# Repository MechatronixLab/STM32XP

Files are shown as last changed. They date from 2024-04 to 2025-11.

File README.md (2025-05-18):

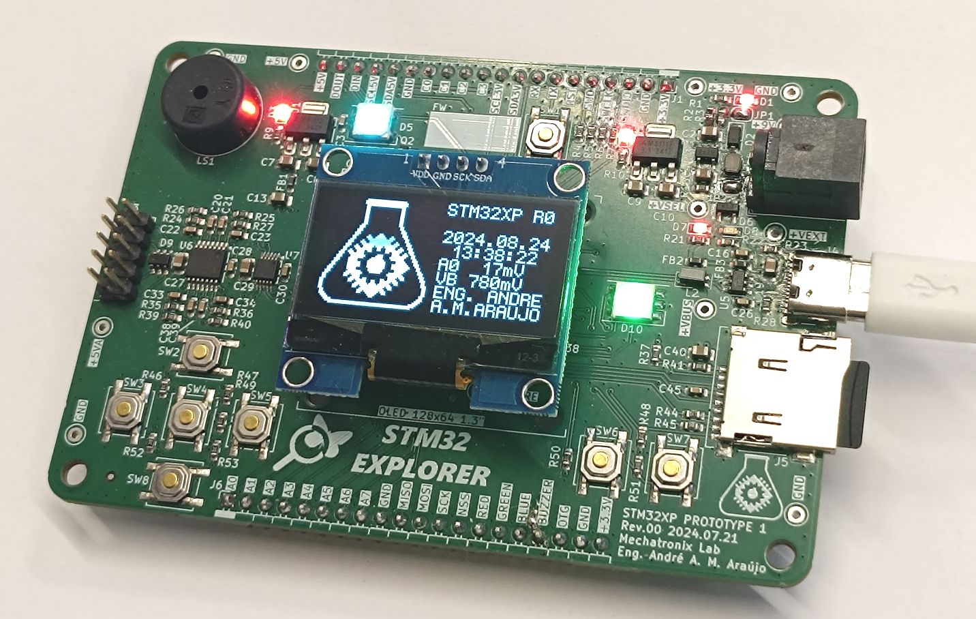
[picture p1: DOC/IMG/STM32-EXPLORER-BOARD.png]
STM32 EXPLORER BOARD


# STM32 Explorer Board - STM32XP
  
This is an educational development board conceived as part of a PCB Design course. The course is offered via [**Portal Embarcados**](https://embarcados.com.br/) website ([**Course Page**](https://cursos.embarcados.com.br/cursos/projeto-de-pcb-para-sistemas-embarcados/)).

## License and certification
This is an open source hardware project licensed under CERN-OHL-P. More details on [LICENSE.md](./LICENSE.md).  
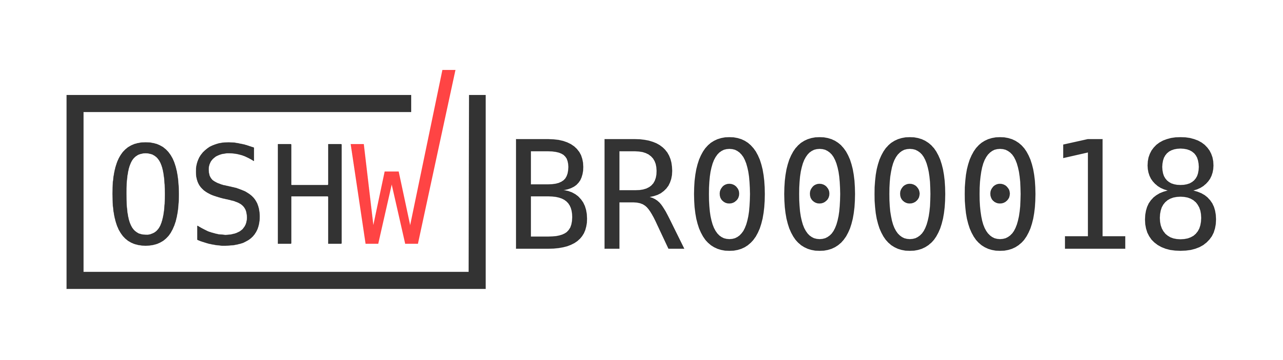
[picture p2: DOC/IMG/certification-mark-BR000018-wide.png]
OSHW BR000018

[OSHW] BR000018 | Certified open source hardware | [oshwa.org/cert](https://certification.oshwa.org/br000018.html).

## Board specifications

The board is based on the [**STM32F411**](https://www.st.com/en/microcontrollers-microprocessors/stm32f411.html), more specifically, the [**STM32F411RET6**](https://www.st.com/en/microcontrollers-microprocessors/stm32f411re.html).
Additionally, the board features some components commonly used in Embedded Systems, such as:
- DC-DC Converters
- OLED Display, connected to the MCU via I²C
- RGB LEDs
- Audio buzzer, controlled via PWM
- External ADC with analog antialiasing filters
- USB 1.1 Full Speed via a Type-C connector
- Micro SD Card for easy data storage, connected to the MCU via SPI
- Input buttons
- Several I/O pins routed to breakout connectors/pins
- CR2032 Battery for RTC operation

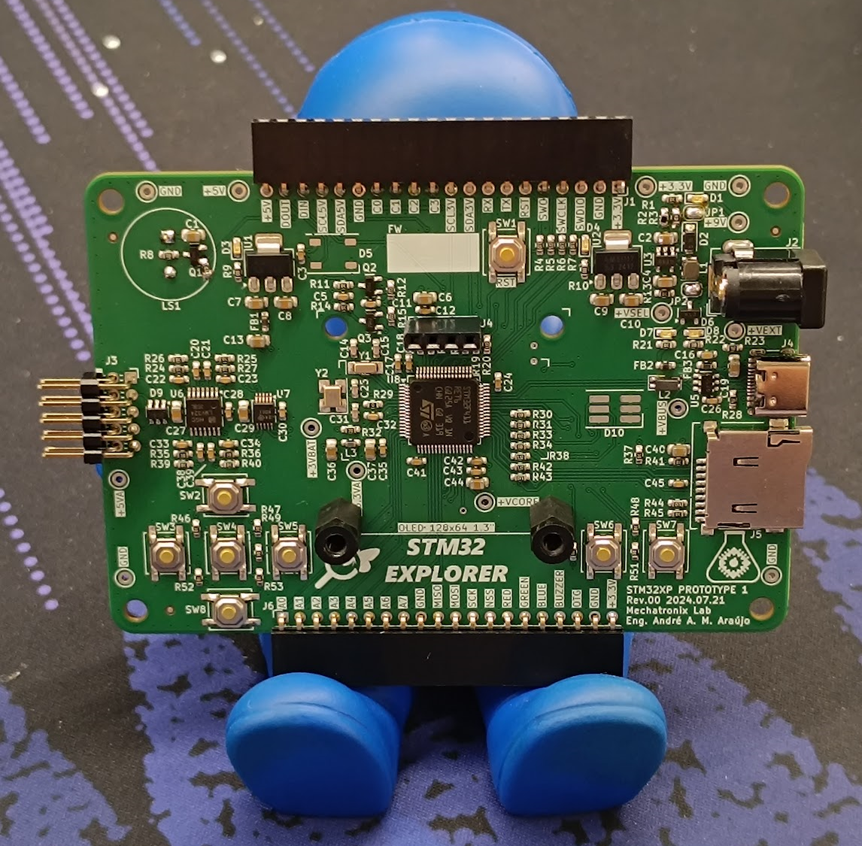
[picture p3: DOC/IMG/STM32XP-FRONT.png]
Front


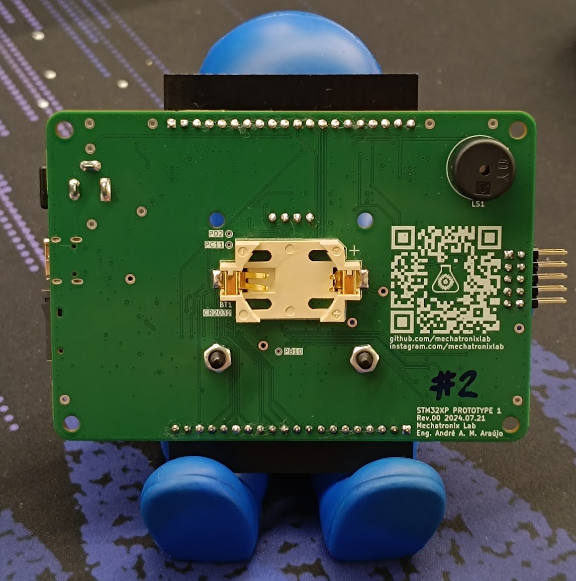
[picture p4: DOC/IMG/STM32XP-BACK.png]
Back

  
## Firmware

A simple software application was developed to test each of the subsystems of the board.

## Tests

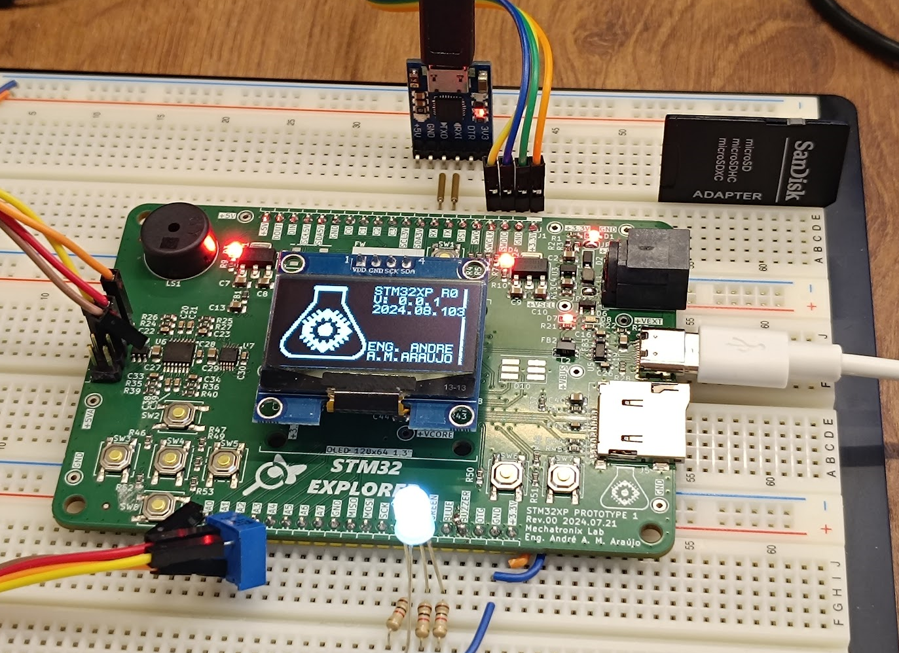
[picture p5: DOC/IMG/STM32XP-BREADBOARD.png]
Breadboard testing


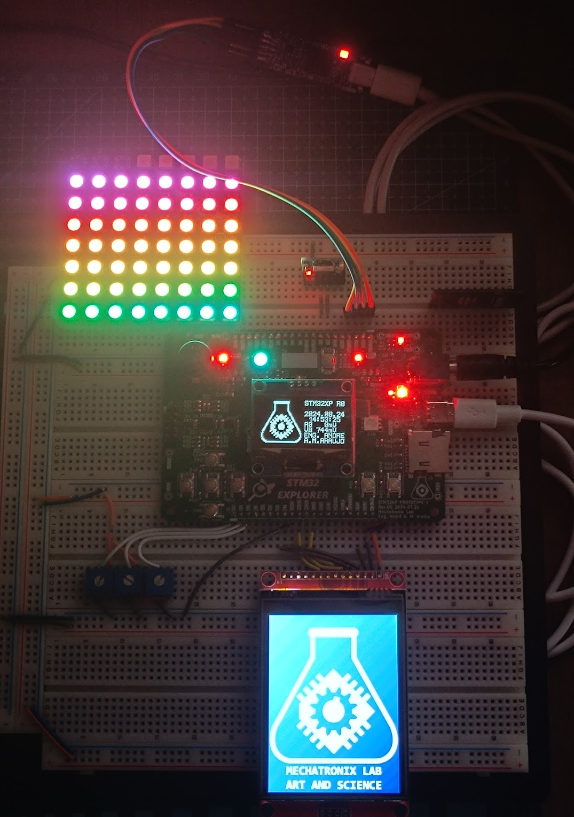
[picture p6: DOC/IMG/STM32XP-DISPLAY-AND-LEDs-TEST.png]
LCD Display and RGB LEDs tests


# Breadboard Prototype

Before commiting to this design, a breadboard prototype was assembled for validation. This prototype used a Nucleo Board, development modules whenever possible, ICs and discrete electronic components. These parts can be easily acquired on electronics stores worldwide. The connections between modules follow very closely the [final schematic](https://github.com/MechatronixLab/STM32XP/blob/master/HARDWARE/KICAD/STM32XP.pdf) of the STM32XP Board. The same firmware runs on both the prototype and STM32XP Board.

Breadboard Prototype  

## Parts list
 
| Part | Image |
|---|:---:|
| [**NUCLEO-F411RE**](https://www.st.com/en/evaluation-tools/nucleo-f411re.html) |  |
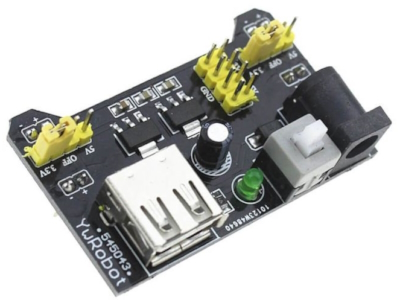
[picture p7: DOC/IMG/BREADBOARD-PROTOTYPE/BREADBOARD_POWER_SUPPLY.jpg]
| Breadboard Power Supply Module |  |
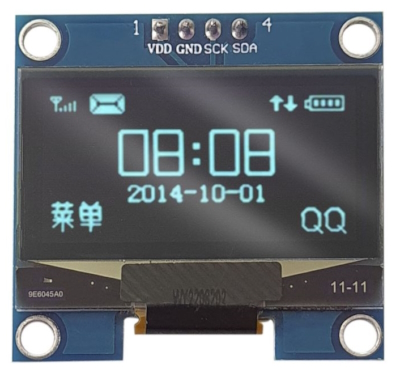
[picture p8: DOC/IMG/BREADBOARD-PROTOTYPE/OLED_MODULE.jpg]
| 1.3" OLED Display Module |  |
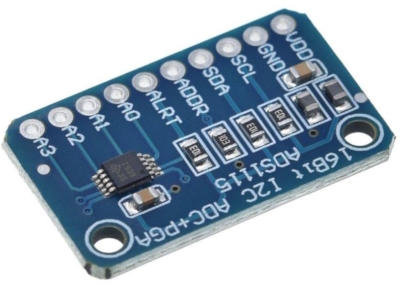
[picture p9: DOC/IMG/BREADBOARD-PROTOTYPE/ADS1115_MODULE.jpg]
| ADS1115 ADC Module |  |
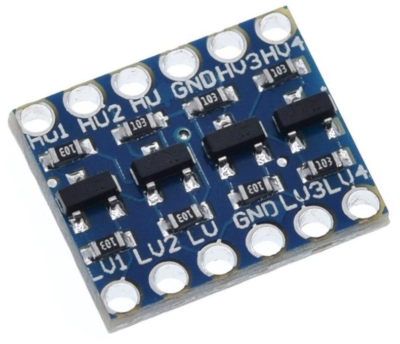
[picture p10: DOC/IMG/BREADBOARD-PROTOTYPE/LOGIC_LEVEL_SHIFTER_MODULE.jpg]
| Bidirectional Level Shifter Module |  |
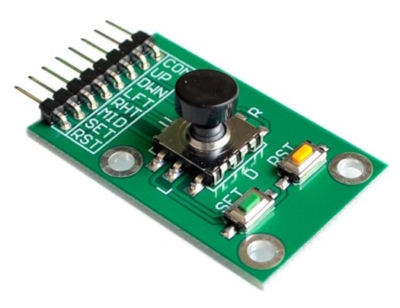
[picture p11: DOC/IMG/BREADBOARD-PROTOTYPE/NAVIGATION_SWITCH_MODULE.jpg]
| Directional Tactile Switch Module |  |
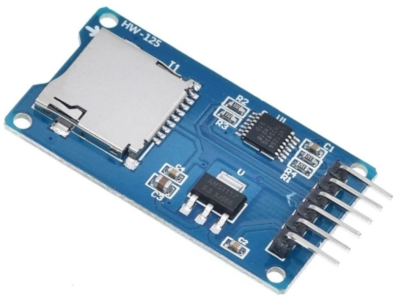
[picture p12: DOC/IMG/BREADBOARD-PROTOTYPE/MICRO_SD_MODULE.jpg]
| Micro SD Card Module |  |
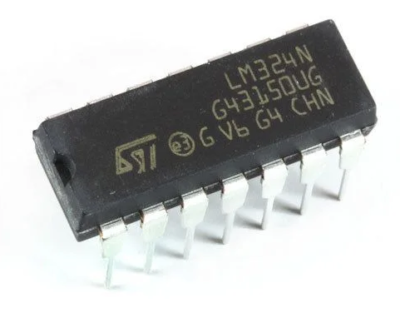
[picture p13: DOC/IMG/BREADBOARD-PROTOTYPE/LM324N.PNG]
| LM324N + Passives (Anti-Aliasing Filter) |  |
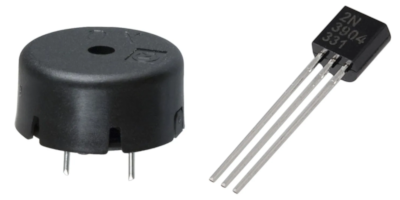
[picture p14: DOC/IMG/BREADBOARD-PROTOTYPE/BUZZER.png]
| Passive Buzzer + 2N3904 |  |
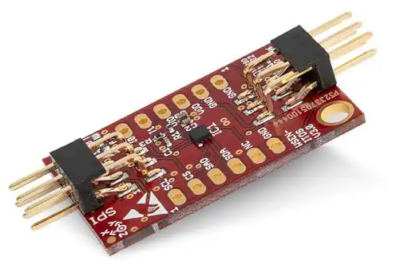
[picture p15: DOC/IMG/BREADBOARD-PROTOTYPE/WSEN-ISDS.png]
| [**WSEN-ISDS**](https://www.we-online.com/en/components/products/WSEN-ISDS) (Left out of the final design)|  |

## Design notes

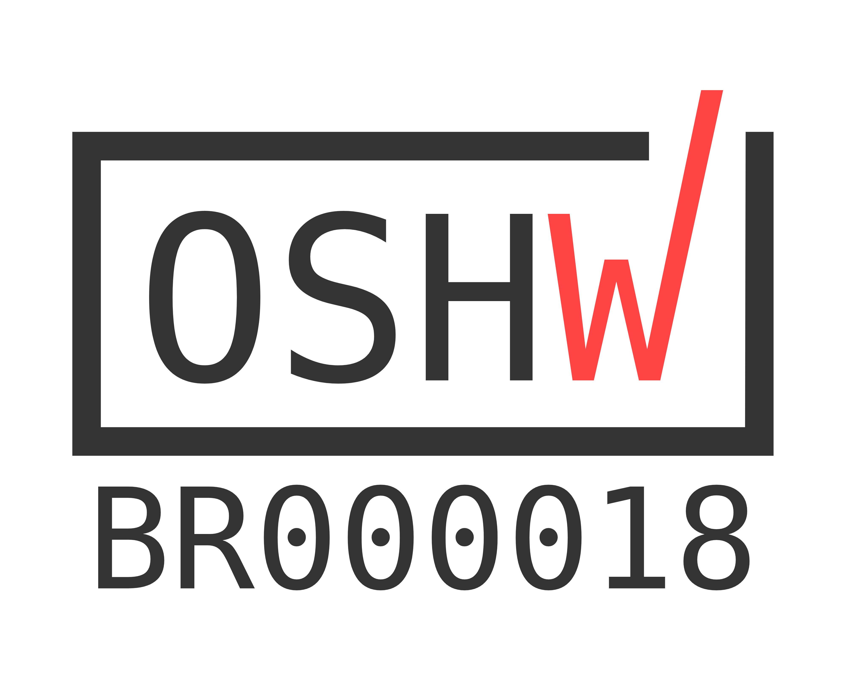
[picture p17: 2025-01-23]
DOC/IMG/certification-mark-BR000018-stacked.png

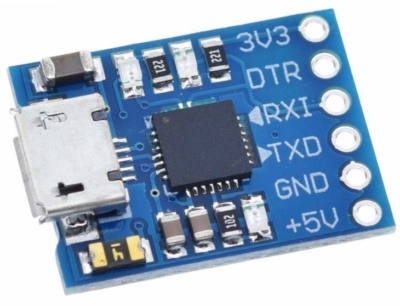
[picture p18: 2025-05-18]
DOC/IMG/BREADBOARD-PROTOTYPE/CP2102_MODULE.jpg

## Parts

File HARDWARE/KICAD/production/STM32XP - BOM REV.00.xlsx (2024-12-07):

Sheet: STM32XP - BOM REV.00
 |  |  |  |  | SPEC |  |  |  |  | JLCPCB
# | DESIGNATOR | VALUE | FOOTPRINT | QTY. | MPN | MANUFACTURER | DATASHEET | 3D MODEL | NOTES | LCSC Part # | LCSC MPN | LCSC MANUFACTURER
1 | BT1 | CR2032 | CR2032 | 1 | 79527141 | WÜRTH ELEKTRONIK | https://www.we-online.com/components/products/datasheet/79527141.pdf | https://www.we-online.com/components/products/download/79527141%20%28rev1%29.igs | - | - | - | -
2 | C1, C10, C13, C19, C2, C27, C29, C36, C37, C4, C40, C44, C6, C7, C8, C9 | 10uF 16V | CAP_0805 | 16 | KGM21AR71C106K | KYOCERA/AVX | https://datasheets.kyocera-avx.com/KGM_X7R.pdf | KICAD CAP 0603 | - | C15850 (https://www.lcsc.com/product-detail/Multilayer-Ceramic-Capacitors-MLCC-SMD-SMT_Samsung-Electro-Mechanics-CL21A106KAYNNNE_C15850.html) | CL21A106KAYNNNE | SAMSUNG
3 | C11, C12, C17, C18, C20, C21, C22, C23, C24, C26, C28, C3, C30, C32, C33, C34, C35, C38, C39, C41, C42, C43, C45, C5 | 100nF 50V | CAP_0603 | 24 | KGM15BR71H104K | KYOCERA/AVX | https://datasheets.kyocera-avx.com/KGM_X7R.pdf | KICAD CAP 0603 | - | C14663 (https://www.lcsc.com/product-detail/Multilayer-Ceramic-Capacitors-MLCC-SMD-SMT_YAGEO-CC0603KRX7R9BB104_C14663.html) | CC0603KRX7R9BB104 | YAGEO
4 | C14, C15, C25, C31 | 10pF 50V | CAP_0603 | 4 | KGM15ACG1H100G | KYOCERA/AVX | https://datasheets.kyocera-avx.com/C0GNP0-KGM.pdf | KICAD CAP 0603 | - | C1634 (https://www.lcsc.com/product-detail/Multilayer-Ceramic-Capacitors-MLCC-SMD-SMT_Samsung-Electro-Mechanics-CL10C100JB8NNNC_C1634.html) | CL10C100JB8NNNC | SAMSUNG
5 | C16 | 680nF 16V | CAP_0603 | 1 | KGM15BR71C684M | KYOCERA/AVX | https://datasheets.kyocera-avx.com/KGM_X7R.pdf | KICAD CAP 0603 | - | C327005 (https://www.lcsc.com/product-detail/Multilayer-Ceramic-Capacitors-MLCC-SMD-SMT_YAGEO-CC0603KRX5R8BB684_C327005.html) | CC0603KRX5R8BB684 | YAGEO
6 | D1, D3, D4, D7, D8 | LED | LED_0603 | 5 | 150060SS55040 | WÜRTH ELEKTRONIK | https://www.we-online.com/components/products/datasheet/150060SS55040.pdf | KICAD LED 0603 | - | C128052 (https://www.lcsc.com/product-detail/LED-Indication-Discrete_Everlight-Elec-19-213-R6C-AM2P1VY-3T_C128052.html) | 19-213/R6C-AM2P1VY/3T | EVERLIGHT
7 | D10 | 150505M173300 | WE 150505M173300 | 1 | 150505M173300 | WÜRTH ELEKTRONIK | https://www.we-online.com/components/products/datasheet/150505M173300.pdf | https://www.we-online.com/components/products/download/Download_IGS-WL-SFTW-150505M173300%20%28rev1%29.igs | - | - | - | -
8 | D2 | STPS1L40-Y | D_SOD-123 | 1 | STPS1L40ZFY | STMICROELECTRONICS | https://www.st.com/resource/en/datasheet/stps1l40-y.pdf | KICAD SOD-123 | - | C82544 (https://www.lcsc.com/product-detail/Schottky-Diodes_Diodes-Incorporated-1N5819HW-7-F_C82544.html) | 1N5819HW-7-F | DIODES INCORPORATED
9 | D5 | WS2812B | LED_WS2812B_PLCC4_5.0x5.0mm_P3.2mm | 1 | 1315050930002 | WÜRTH ELEKTRONIK | https://www.we-online.com/components/products/datasheet/1315050930002.pdf | https://www.we-online.com/components/products/download/IGS_WL-ICLED_1315050930002%20%28rev1%29.igs | - | - | - | -
10 | D6 | BAT54C | SOT-23 | 1 | BAT54C-7-F | DIODES INCORPORATED | https://www.diodes.com/datasheet/download/BAT54C.pdf | KICAD SOT-23-3 | CHANGE TO 2X 1N5819HW | C916424 (https://www.lcsc.com/product-detail/Schottky-Diodes_JSMSEMI-BAT54C_C916424.html) | BAT54C | JSMSEMI
11 | D9 | ESDA6V1-5SC6 | SOT-23-6 | 1 | ESDA6V1-5SC6 | STMICROELECTRONICS | https://www.st.com/resource/en/datasheet/esda6v1-5sc6.pdf | KICAD SOT-23-6 | - | C2827672 (https://www.lcsc.com/product-detail/ESD-and-Surge-Protection-TVS-ESD_TECH-PUBLIC-ESDA6V1-5SC6_C2827672.html) | ESDA6V1-5SC6 | TECH PUBLIC
12 | FB1, FB2, FB3 | 600R | 0603 | 3 | 742792651 | WÜRTH ELEKTRONIK | https://www.we-online.com/components/products/datasheet/742792651.pdf | KICAD FB 0603 | - | C963865 (https://www.lcsc.com/product-detail/Ferrite-Beads_HYHONGYEX-ACMS160808A1213A_C963865.html) | ACMS160808A1213A | HYHONGYEX
13 | FID1, FID2, FID3 | Fiducial | Fiducial_0.75mm_Mask1.5mm | 3 | - | - | - | - | DO NOT PLACE | - | - | -
14 | H1, H2, H3, H4 | MountingHole | MountingHole_3.2mm_M3 | 4 | - | - | - | - | DO NOT PLACE | - | - | -
15 | J1, J6 | Conn_01x20_Socket | PinSocket_1x20_P2.54mm_Horizontal | 2 | 613020143121 | WÜRTH ELEKTRONIK | https://www.we-online.com/components/products/datasheet/613020143121.pdf | https://www.we-online.com/components/products/download/613020143121%20%28rev1%29.igs | THRU HOLE | - | - | -
16 | J2 | Jack-DC | BarrelJack_GCT_DCJ200-10-A_Horizontal | 1 | 694108301002 | WÜRTH ELEKTRONIK | https://www.we-online.com/components/products/datasheet/694108301002.pdf | https://www.we-online.com/components/products/download/Download_IGES_694108301002%20%28rev1%29.iges | THRU HOLE | - | - | -
17 | J3 | Conn_02x05_Odd_Even | PinSocket_2x05_P2.54mm_Horizontal | 1 | 613010243121 | WÜRTH ELEKTRONIK | https://www.we-online.com/components/products/datasheet/613010243121.pdf | https://www.we-online.com/components/products/download/Downloads_613010243121%20%28rev1%29.iges | THRU HOLE | - | - | -
18 | J4 | USB TYPE C | USB_C_Receptacle_G-Switch_GT-USB-7010ASV | 1 | 629722000214 | WÜRTH ELEKTRONIK | https://www.we-online.com/components/products/datasheet/629722000214.pdf | https://www.we-online.com/components/products/download/IGES_629722000214%20%28rev1%29.iges | - | C2927038 (https://www.lcsc.com/product-detail/USB-Connectors_DEALON-USB-TYPE-C-018_C2927038.html) | USB-TYPE-C-018 | DEALON
19 | J5 | MICRO SD | WE 693071020811 | 1 | 693071020811 | WÜRTH ELEKTRONIK | https://www.we-online.com/components/products/datasheet/693071020811.pdf | https://www.we-online.com/components/products/download/Download_IGES_693071020811%20%28rev1%29.iges | - | C19189038 (https://www.lcsc.com/product-detail/SD-Card-Memory-Card-Connector_hanxia-HX-TF-CARD-H1-8-SY_C19189038.html) | HX TF-CARD H1.8 SY | HANXIA
20 | JP1 | 9V | SolderJumper | 1 | - | - | - | - | DO NOT PLACE | - | - | -
21 | JP2 | VSEL | SolderJumper | 1 | - | - | - | - | DO NOT PLACE | - | - | -
22 | L1 | 10uH | WE 74404024100 | 1 | 74404024100 | WÜRTH ELEKTRONIK | https://www.we-online.com/components/products/datasheet/74404024100.pdf | https://www.we-online.com/components/products/download/WE-LQS_252012%20%28rev1%29.igs | - | C520138 (https://www.lcsc.com/product-detail/Power-Inductors_Cybermax-CMLW252012P100MST_C520138.html) | CMLW252012P100MST | CYBERMAX
23 | L2 | 744232090 | WE 744232090 | 1 | 744232090 | WÜRTH ELEKTRONIK | https://www.we-online.com/components/products/datasheet/744232090.pdf | https://www.we-online.com/components/products/download/WE-CNSW_1206_CNSW%20%28rev1%29.igs | - | - | - | -
24 | L3 | L_Small | IND_0603 | 1 | 742792651 | WÜRTH ELEKTRONIK | https://www.we-online.com/components/products/datasheet/742792651.pdf | KICAD FB 0603 | - | C963865 (https://www.lcsc.com/product-detail/Ferrite-Beads_HYHONGYEX-ACMS160808A1213A_C963865.html) | ACMS160808A1213A | HYHONGYEX
25 | LS1 | 78dB 4kHz | PKM13EPYH4000-A0 | 1 | PKM13EPYH4000-A0 | MURATA | https://www.murata.com/en-us/products/productdetail?partno=PKM13EPYH4000-A0 | https://www.murata.com/en-us/products/productdetail?partno=PKM13EPYH4000-A0 | THRU HOLE | - | - | -
26 | Q1, Q2, Q3 | 2N7002 | SOT-23 | 3 | 2N7002K-7 | DIODES INCORPORATED | https://www.diodes.com/datasheet/download/2N7002K.pdf | KICAD SOT-23-3 | - | C8545 (https://www.lcsc.com/product-detail/MOSFETs_Jiangsu-Changjing-Electronics-Technology-Co-Ltd-2N7002_C8545.html) | 2N7002 | JIANGSU CHANGJING
27 | R1, R11, R13, R14, R18, R2, R21, R24, R25, R26, R27, R32, R35, R36, R37, R39, R40, R41, R45, R46, R47, R48, R49, R50, R51, R52, R53 | 10K 1% | RES_0603 | 27 | CRCW060310K0FK | VISHAY | https://www.we-online.com/components/products/datasheet/61300411821.pdf | KICCAD RES 0603 | - | C25804 (https://www.lcsc.com/product-detail/Chip-Resistor-Surface-Mount_UNI-ROYAL-Uniroyal-Elec-0603WAF1002T5E_C25804.html) | 0603WAF1002T5E | UNI-ROYAL
28 | R10, R22, R30, R31, R33, R34, R8, R9 | 1K 1% | RES_0603 | 8 | CRCW06031K00FK | VISHAY | https://www.we-online.com/components/products/datasheet/61300411821.pdf | KICCAD RES 0603 | - | C21190 (https://www.lcsc.com/product-detail/Chip-Resistor-Surface-Mount_UNI-ROYAL-Uniroyal-Elec-0603WAF1001T5E_C21190.html) | 0603WAF1001T5E | UNI-ROYAL
29 | R12, R15 | 2.2K 1% | RES_0603 | 2 | CRCW06032K20FK | VISHAY | https://www.we-online.com/components/products/datasheet/61300411821.pdf | KICCAD RES 0603 | - | C4190 (https://www.lcsc.com/product-detail/Chip-Resistor-Surface-Mount_UNI-ROYAL-Uniroyal-Elec-0603WAF2201T5E_C4190.html) | 0603WAF2201T5E | UNI-ROYAL
30 | R16, R17, R19, R20, R38, R4, R42, R43, R44, R5, R6, R7 | 51R 1% | RES_0603 | 12 | CRCW060351R0FK | VISHAY | https://www.we-online.com/components/products/datasheet/61300411821.pdf | KICCAD RES 0603 | - | C23197 (https://www.lcsc.com/product-detail/Chip-Resistor-Surface-Mount_UNI-ROYAL-Uniroyal-Elec-0603WAF510JT5E_C23197.html) | 0603WAF510JT5E | UNI-ROYAL
31 | R23, R28 | 5.1K 1% | RES_0603 | 2 | CRCW06035K10FK | VISHAY | https://www.we-online.com/components/products/datasheet/61300411821.pdf | KICCAD RES 0603 | - | C23186 (https://www.lcsc.com/product-detail/Chip-Resistor-Surface-Mount_UNI-ROYAL-Uniroyal-Elec-0603WAF5101T5E_C23186.html) | 0603WAF5101T5E | UNI-ROYAL
32 | R29 | 0R | RES_0603 | 1 | CRCW06030000Z0 | VISHAY | https://www.we-online.com/components/products/datasheet/61300411821.pdf | KICCAD RES 0603 | - | C21189 (https://www.lcsc.com/product-detail/Chip-Resistor-Surface-Mount_UNI-ROYAL-Uniroyal-Elec-0603WAF0000T5E_C21189.html) | 0603WAF0000T5E | UNI-ROYAL
33 | R3 | 6K2 1% | RES_0603 | 1 | CRCW06036K20FK | VISHAY | https://www.we-online.com/components/products/datasheet/61300411821.pdf | KICCAD RES 0603 | - | C4260 (https://www.lcsc.com/product-detail/Chip-Resistor-Surface-Mount_UNI-ROYAL-Uniroyal-Elec-0603WAF6201T5E_C4260.html) | 0603WAF6201T5E | UNI-ROYAL
34 | SW1 | RST | SW_Push_1P1T_NO_CK_KSC6xxJ | 1 | PTS526SM20SMTR21 LFS | LITTELFUSE/C&K | https://www.ckswitches.com/media/2780/pts526.pdf | https://www.ckswitches.com/products/switches/product-details/Tactile/PTS526/PTS526SM20SMTR21%20LFS/ | ${KICAD8_3DMODEL_DIR}/Button_Switch_SMD.3dshapes/SW_SPST_TL3342.step | C318884 (https://www.lcsc.com/product-detail/Tactile-Switches_XKB-Connection-TS-1187A-B-A-B_C318884.html) | TS-1187A-B-A-B | XKB CONNECTION
35 | SW2 | UP | SW_Push_1P1T_NO_CK_KSC6xxJ | 1 | PTS526SM20SMTR21 LFS | LITTELFUSE/C&K | https://www.ckswitches.com/media/2780/pts526.pdf | https://www.ckswitches.com/products/switches/product-details/Tactile/PTS526/PTS526SM20SMTR21%20LFS/ | ${KICAD8_3DMODEL_DIR}/Button_Switch_SMD.3dshapes/SW_SPST_TL3342.step | C318884 (https://www.lcsc.com/product-detail/Tactile-Switches_XKB-Connection-TS-1187A-B-A-B_C318884.html) | TS-1187A-B-A-B | XKB CONNECTION
36 | SW3 | LEFT | SW_Push_1P1T_NO_CK_KSC6xxJ | 1 | PTS526SM20SMTR21 LFS | LITTELFUSE/C&K | https://www.ckswitches.com/media/2780/pts526.pdf | https://www.ckswitches.com/products/switches/product-details/Tactile/PTS526/PTS526SM20SMTR21%20LFS/ | ${KICAD8_3DMODEL_DIR}/Button_Switch_SMD.3dshapes/SW_SPST_TL3342.step | C318884 | TS-1187A-B-A-B | XKB CONNECTION
37 | SW4 | CENTER | SW_Push_1P1T_NO_CK_KSC6xxJ | 1 | PTS526SM20SMTR21 LFS | LITTELFUSE/C&K | https://www.ckswitches.com/media/2780/pts526.pdf | https://www.ckswitches.com/products/switches/product-details/Tactile/PTS526/PTS526SM20SMTR21%20LFS/ | ${KICAD8_3DMODEL_DIR}/Button_Switch_SMD.3dshapes/SW_SPST_TL3342.step | C318884 | TS-1187A-B-A-B | XKB CONNECTION
38 | SW5 | RIGHT | SW_Push_1P1T_NO_CK_KSC6xxJ | 1 | PTS526SM20SMTR21 LFS | LITTELFUSE/C&K | https://www.ckswitches.com/media/2780/pts526.pdf | https://www.ckswitches.com/products/switches/product-details/Tactile/PTS526/PTS526SM20SMTR21%20LFS/ | ${KICAD8_3DMODEL_DIR}/Button_Switch_SMD.3dshapes/SW_SPST_TL3342.step | C318884 | TS-1187A-B-A-B | XKB CONNECTION
39 | SW6 | BUTTON 1 | SW_Push_1P1T_NO_CK_KSC6xxJ | 1 | PTS526SM20SMTR21 LFS | LITTELFUSE/C&K | https://www.ckswitches.com/media/2780/pts526.pdf | https://www.ckswitches.com/products/switches/product-details/Tactile/PTS526/PTS526SM20SMTR21%20LFS/ | ${KICAD8_3DMODEL_DIR}/Button_Switch_SMD.3dshapes/SW_SPST_TL3342.step | C318884 | TS-1187A-B-A-B | XKB CONNECTION
40 | SW7 | BUTTON 2 | SW_Push_1P1T_NO_CK_KSC6xxJ | 1 | PTS526SM20SMTR21 LFS | LITTELFUSE/C&K | https://www.ckswitches.com/media/2780/pts526.pdf | https://www.ckswitches.com/products/switches/product-details/Tactile/PTS526/PTS526SM20SMTR21%20LFS/ | ${KICAD8_3DMODEL_DIR}/Button_Switch_SMD.3dshapes/SW_SPST_TL3342.step | C318884 | TS-1187A-B-A-B | XKB CONNECTION
41 | SW8 | DOWN | SW_Push_1P1T_NO_CK_KSC6xxJ | 1 | PTS526SM20SMTR21 LFS | LITTELFUSE/C&K | https://www.ckswitches.com/media/2780/pts526.pdf | https://www.ckswitches.com/products/switches/product-details/Tactile/PTS526/PTS526SM20SMTR21%20LFS/ | ${KICAD8_3DMODEL_DIR}/Button_Switch_SMD.3dshapes/SW_SPST_TL3342.step | C318884 | TS-1187A-B-A-B | XKB CONNECTION
42 | TP1, TP13, TP14, TP4 | GND | TestPoint_Keystone_5000-5004_Miniature | 4 | - | - | - | - | DO NOT PLACE | - | - | -
43 | TP10 | +3.3VA | TestPoint_Keystone_5000-5004_Miniature | 1 | - | - | - | - | DO NOT PLACE | - | - | -
44 | TP11 | +5VA | TestPoint_Keystone_5000-5004_Miniature | 1 | - | - | - | - | DO NOT PLACE | - | - | -
45 | TP12 | +VCORE | TestPoint_Keystone_5000-5004_Miniature | 1 | - | - | - | - | DO NOT PLACE | - | - | -
46 | TP15 | PD2 | TestPoint_THTPad_D1.0mm_Drill0.5mm | 1 | - | - | - | - | DO NOT PLACE | - | - | -
47 | TP16 | PC11 | TestPoint_THTPad_D1.0mm_Drill0.5mm | 1 | - | - | - | - | DO NOT PLACE | - | - | -
48 | TP17 | PC12 | TestPoint_THTPad_D1.0mm_Drill0.5mm | 1 | - | - | - | - | DO NOT PLACE | - | - | -
49 | TP18 | PB5 | TestPoint_THTPad_D1.0mm_Drill0.5mm | 1 | - | - | - | - | DO NOT PLACE | - | - | -
50 | TP19 | PB4 | TestPoint_THTPad_D1.0mm_Drill0.5mm | 1 | - | - | - | - | DO NOT PLACE | - | - | -
51 | TP2 | +5V | TestPoint_Keystone_5000-5004_Miniature | 1 | - | - | - | - | DO NOT PLACE | - | - | -
52 | TP20 | PC13 | TestPoint_THTPad_D1.0mm_Drill0.5mm | 1 | - | - | - | - | DO NOT PLACE | - | - | -
53 | TP21 | PB10 | TestPoint_THTPad_D1.0mm_Drill0.5mm | 1 | - | - | - | - | DO NOT PLACE | - | - | -
54 | TP3 | +3.3V | TestPoint_Keystone_5000-5004_Miniature | 1 | - | - | - | - | DO NOT PLACE | - | - | -
55 | TP5 | +9V | TestPoint_Keystone_5000-5004_Miniature | 1 | - | - | - | - | DO NOT PLACE | - | - | -
56 | TP6 | +VSEL | TestPoint_Keystone_5000-5004_Miniature | 1 | - | - | - | - | DO NOT PLACE | - | - | -
57 | TP7 | +VEXT | TestPoint_Keystone_5000-5004_Miniature | 1 | - | - | - | - | DO NOT PLACE | - | - | -
58 | TP8 | +VBUS | TestPoint_Keystone_5000-5004_Miniature | 1 | - | - | - | - | DO NOT PLACE | - | - | -
59 | TP9 | +3VBAT | TestPoint_Keystone_5000-5004_Miniature | 1 | - | - | - | - | DO NOT PLACE | - | - | -
60 | U1 | AMS1117-5.0 | SOT-223-3 | 1 | LD1117S50TR | STMICROELECTRONICS | https://www.st.com/resource/en/datasheet/ld1117.pdf | KICAD STO-223-3 | - | C6187 (https://www.lcsc.com/product-detail/Voltage-Regulators-Linear-Low-Drop-Out-LDO-Regulators_Advanced-Monolithic-Systems-AMS1117-5-0_C6187.html) | AMS1117-5.0 | ADVANCED MONOLITHIC SYSTEMS
61 | U2 | AMS1117-3.3 | SOT-223-3 | 1 | LD1117S33TR | STMICROELECTRONICS | https://www.st.com/resource/en/datasheet/ld1117.pdf | KICAD STO-223-3 | - | C6186 (https://www.lcsc.com/product-detail/Voltage-Regulators-Linear-Low-Drop-Out-LDO-Regulators_Advanced-Monolithic-Systems-AMS1117-3-3_C6186.html) | AMS1117-3.3 | ADVANCED MONOLITHIC SYSTEMS
62 | U3 | AP3012 | SOT-23-5 | 1 | AP3012KTR-E1 | DIODES INCORPORATED | https://www.diodes.com/datasheet/download/AP3012.pdf | KICAD SOT-23-5 | - | C460356 (https://www.lcsc.com/product-detail/DC-DC-Converters_Diodes-Incorporated-AP3012KTR-E1_C460356.html) | AP3012KTR-E1 | DIODES INCORPORATED
63 | U4 | OLED 128x64 1.3" | OLED 128x64 1.3in | 1 | 61300411821 | WÜRTH ELEKTRONIK | https://www.we-online.com/components/products/datasheet/61300411821.pdf | https://www.we-online.com/components/products/download/61300411821%20%28rev1%29.iges | THRU HOLE; https://grabcad.com/library/oled-screen-1-3-1 | - | - | -
64 | U5 | USBLC6-2SC6 | SOT-23-6 | 1 | USBLC6-2SC6 | STMICROELECTRONICS | https://www.st.com/resource/en/datasheet/usblc6-2sc6y.pdf | KICAD SOT-23-6 | - | C2827654 (https://www.lcsc.com/product-detail/ESD-and-Surge-Protection-TVS-ESD_TECH-PUBLIC-USBLC6-2SC6_C2827654.html) | USBLC6-2SC6 | TECH PUBLIC
65 | U6 | LM324 | TSSOP-14_4.4x5mm_P0.65mm | 1 | LMV324IPT | STMICROELECTRONICS | https://www.st.com/resource/en/datasheet/lmv324.pdf | KICAD TSSOP-14 | - | C398929 (https://www.lcsc.com/product-detail/Operational-Amplifier_Texas-Instruments-LMV324IPWR_C398929.html) | LMV324IPWR | TEXAS INSTRUMENTS
66 | U7 | ADS1115IDGS | TSSOP-10_3x3mm_P0.5mm | 1 | ADS1115IDGSR | TEXAS INSTRUMENTS | https://www.ti.com/lit/ds/symlink/ads1115.pdf | KICAD TSSOP-10 | - | C37593 (https://www.lcsc.com/product-detail/Analog-to-Digital-Converters-ADC_Texas-Instruments-ADS1115IDGSR_C37593.html) | ADS1115IDGSR | TEXAS INSTRUMENTS
67 | U8 | STM32F411RETx | LQFP-64_10x10mm_P0.5mm | 1 | STM32F411RET6 | STMICROELECTRONICS | https://www.st.com/resource/en/datasheet/stm32f411re.pdf | KICAD LQFP-64 | - | C94355 (https://www.lcsc.com/product-detail/Microcontrollers-MCU-MPU-SOC_STMicroelectronics-STM32F411RET6_C94355.html) | STM32F411RET6 | STMICROELECTRONICS
68 | Y1 | 32.768kHz 12.5pF | XTAL_2PIN_3.2x1.5mm | 1 | ABS06-32.768KHZ-T | ABRACON/FOX | https://abracon.com/Resonators/ABS06.pdf | KICAD XTAL 3.2x1.5 | - | C5563819 (https://www.lcsc.com/product-detail/Crystals_HCI-3131M-32768DT06LLL_C5563819.html) | 3131M-32768DT06LLL | HCI
69 | Y2 | 12MHz 20ppm 18pF | XTAL_4PIN_3.2x2.5mm | 1 | ABM8-12.000MHZ-D2Y-T | ABRACON/FOX | https://abracon.com/Resonators/abm8.pdf | KICAD XTAL 3.2x2.5 | - | C6071564 (https://www.lcsc.com/product-detail/Crystals_SST-3225-12M-18PF-20PPM_C6071564.html) | 3225 12M 18PF 20PPM | SST
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

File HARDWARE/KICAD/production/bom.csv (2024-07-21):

Designator | Footprint | Quantity | Value | LCSC Part #
BT1 | BatteryHolder_Keystone_1060_1x2032 | 1 | CR2032
C1, C10, C13, C19, C2, C27, C29, C36, C37, C4, C40, C44, C6, C7, C8, C9 | 0805 | 16 | 10uF 25V
C11, C12, C17, C18, C20, C21, C22, C23, C24, C26, C28, C3, C30, C32, C33, C34, C35, C38, C39, C41, C42, C43, C45, C5 | 0603 | 24 | 100nF 50V
C14, C15, C25, C31 | 0603 | 4 | 10pF 50V
C16 | 0603 | 1 | 680nF 16V
D1, D3, D4, D7, D8 | 0603 | 5 | LED
D10 | WE 150505M173300 | 1 | 150505M173300
D2 | D_SOD-123 | 1 | STPS1L40-Y
D5 | LED_WS2812B_PLCC4_5.0x5.0mm_P3.2mm | 1 | WS2812B
D6 | SOT-23 | 1 | BAT54C
D9 | SOT-23-6 | 1 | ESDA6V1-5SC6
FB1, FB2, FB3 | 0603 | 3 | 600R
FID1, FID2, FID3 | Fiducial_0.75mm_Mask1.5mm | 3 | Fiducial
H1, H2, H3, H4 | MountingHole_3.2mm_M3 | 4 | MountingHole
J1, J6 | PinSocket_1x20_P2.54mm_Horizontal | 2 | Conn_01x20_Socket
J2 | BarrelJack_GCT_DCJ200-10-A_Horizontal | 1 | Jack-DC
J3 | PinSocket_2x05_P2.54mm_Horizontal | 1 | Conn_02x05_Odd_Even
J4 | USB_C_Receptacle_G-Switch_GT-USB-7010ASV | 1 | USB TYPE C
J5 | WE 693071020811 | 1 | MICRO SD
JP1 | SolderJumper-2_P1.3mm_Open_RoundedPad1.0x1.5mm | 1 | 9V
JP2 | SolderJumper-2_P1.3mm_Open_RoundedPad1.0x1.5mm | 1 | VSEL
L1 | WE 74404024100 | 1 | 10uH
L2 | WE 744232090 | 1 | 744232090
L3 | 0603 | 1 | L_Small
LS1 | PKM13EPYH4000-A0 | 1 | 78dB 4kHz
Q1, Q2, Q3 | SOT-23 | 3 | 2N7002
R1, R11, R13, R14, R18, R2, R21, R24, R25, R26, R27, R32, R35, R36, R37, R39, R40, R41, R45, R46, R47, R48, R49, R50, R51, R52, R53 | 0603 | 27 | 10K 1%
R10, R22, R30, R31, R33, R34, R8, R9 | 0603 | 8 | 1K 1%
R12, R15 | 0603 | 2 | 2.2K 1%
R16, R17, R19, R20, R38, R4, R42, R43, R44, R5, R6, R7 | 0603 | 12 | 51R 1%
R23, R28 | 0603 | 2 | 5.1K 1%
R29 | 0603 | 1 | 0R
R3 | 0603 | 1 | 6K2 1%
SW1 | SW_Push_1P1T_NO_CK_KSC6xxJ | 1 | RST
SW2 | SW_Push_1P1T_NO_CK_KSC6xxJ | 1 | UP
SW3 | SW_Push_1P1T_NO_CK_KSC6xxJ | 1 | LEFT
SW4 | SW_Push_1P1T_NO_CK_KSC6xxJ | 1 | CENTER
SW5 | SW_Push_1P1T_NO_CK_KSC6xxJ | 1 | RIGHT
SW6 | SW_Push_1P1T_NO_CK_KSC6xxJ | 1 | BUTTON 1
SW7 | SW_Push_1P1T_NO_CK_KSC6xxJ | 1 | BUTTON 2
SW8 | SW_Push_1P1T_NO_CK_KSC6xxJ | 1 | DOWN
TP1, TP13, TP14, TP4 | TestPoint_Keystone_5000-5004_Miniature | 4 | GND
TP10 | TestPoint_Keystone_5000-5004_Miniature | 1 | +3.3VA
TP11 | TestPoint_Keystone_5000-5004_Miniature | 1 | +5VA
TP12 | TestPoint_Keystone_5000-5004_Miniature | 1 | +VCORE
TP15 | TestPoint_THTPad_D1.0mm_Drill0.5mm | 1 | PD2
TP16 | TestPoint_THTPad_D1.0mm_Drill0.5mm | 1 | PC11
TP17 | TestPoint_THTPad_D1.0mm_Drill0.5mm | 1 | PC12
TP18 | TestPoint_THTPad_D1.0mm_Drill0.5mm | 1 | PB5
TP19 | TestPoint_THTPad_D1.0mm_Drill0.5mm | 1 | PB4
TP2 | TestPoint_Keystone_5000-5004_Miniature | 1 | +5V
TP20 | TestPoint_THTPad_D1.0mm_Drill0.5mm | 1 | PC13
TP21 | TestPoint_THTPad_D1.0mm_Drill0.5mm | 1 | PB10
TP3 | TestPoint_Keystone_5000-5004_Miniature | 1 | +3.3V
TP5 | TestPoint_Keystone_5000-5004_Miniature | 1 | +9V
TP6 | TestPoint_Keystone_5000-5004_Miniature | 1 | +VSEL
TP7 | TestPoint_Keystone_5000-5004_Miniature | 1 | +VEXT
TP8 | TestPoint_Keystone_5000-5004_Miniature | 1 | +VBUS
TP9 | TestPoint_Keystone_5000-5004_Miniature | 1 | +3VBAT
U1 | SOT-223-3_TabPin2 | 1 | AMS1117-5.0
U2 | SOT-223-3_TabPin2 | 1 | AMS1117-3.3
U3 | SOT-23-5 | 1 | AP3012
U4 | OLED 128x64 1.3in | 1 | OLED 128x64 1.3"
U5 | SOT-23-6 | 1 | USBLC6-2SC6
U6 | TSSOP-14_4.4x5mm_P0.65mm | 1 | LM324
U7 | TSSOP-10_3x3mm_P0.5mm | 1 | ADS1115IDGS
U8 | LQFP-64_10x10mm_P0.5mm | 1 | STM32F411RETx
Y1 | Crystal_SMD_G8-2Pin_3.2x1.5mm_HandSoldering | 1 | 32.768kHz
Y2 | Crystal_SMD_EuroQuartz_MT-4Pin_3.2x2.5mm_HandSoldering | 1 | 8MHz 20Pppm 18pF

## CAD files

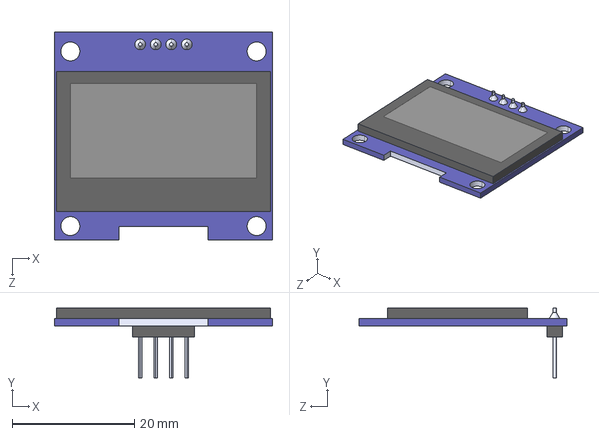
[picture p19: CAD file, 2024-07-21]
HARDWARE/KICAD/3D/Display_OLED_SSD1306_1.3inch.STEP
35.7 x 11.4 x 34.0 mm

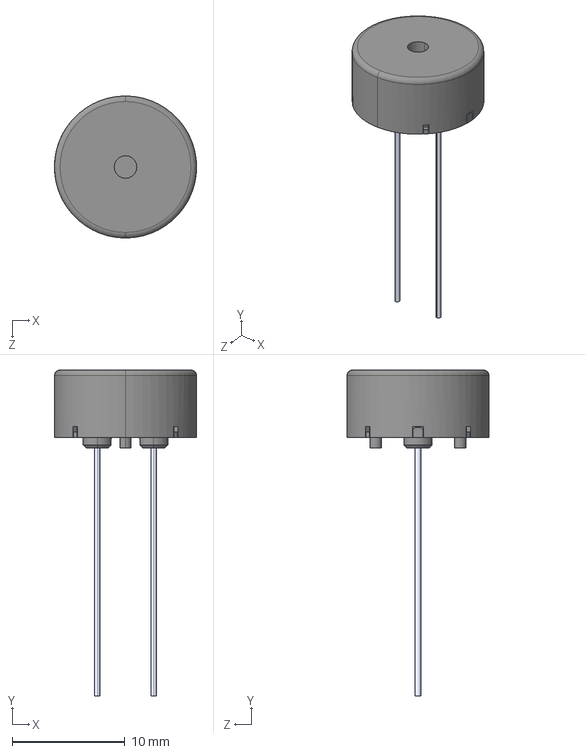
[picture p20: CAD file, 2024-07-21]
HARDWARE/KICAD/3D/MURATA PKM13EPYH4000-A0.STEP
12.6 x 28.9 x 12.6 mm

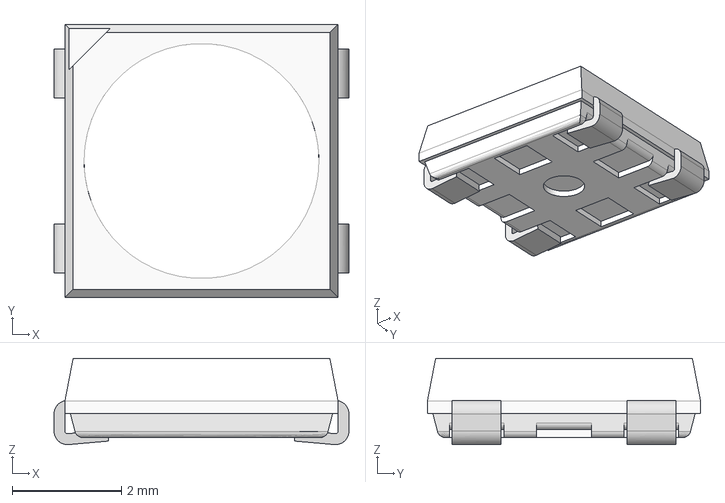
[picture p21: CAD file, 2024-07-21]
HARDWARE/KICAD/3D/WE WL-ICLED_1315050930002 IC RGB LED.igs
5.40 x 5.00 x 1.58 mm

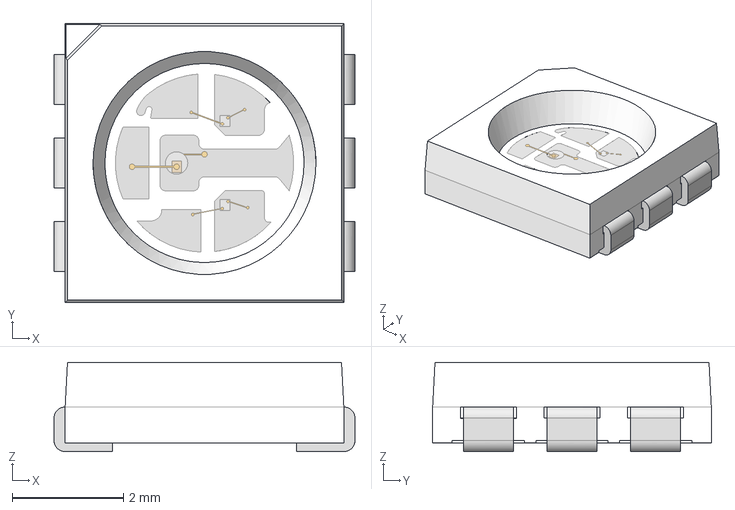
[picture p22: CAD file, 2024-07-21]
HARDWARE/KICAD/3D/WE WL-SFTW-150505M173300 RGB LED PLCC 5050.igs
5.40 x 5.00 x 1.60 mm

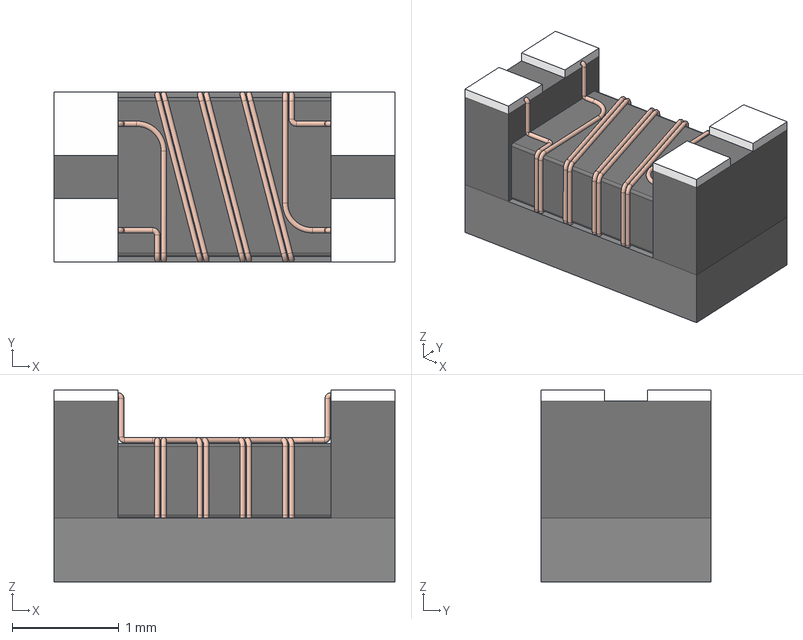
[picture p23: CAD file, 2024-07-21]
HARDWARE/KICAD/3D/WE CNSW_1206_CNSW.igs
3.20 x 1.60 x 1.80 mm

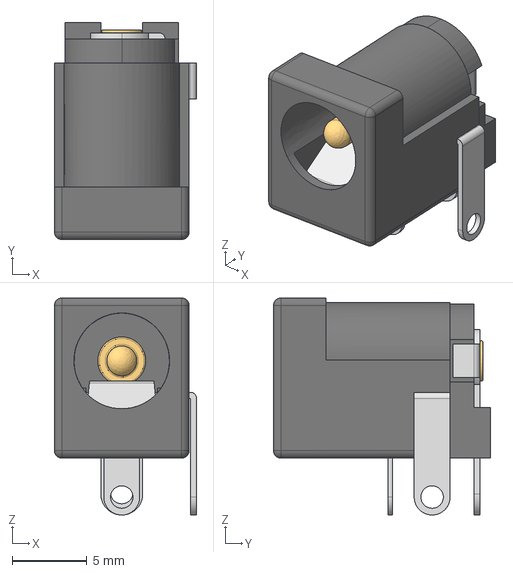
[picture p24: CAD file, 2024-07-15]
HARDWARE/KICAD/3D/WE 694106301002 DC JACK 6.4mm 5.5 X 2.0.iges
9.50 x 14.5 x 14.5 mm

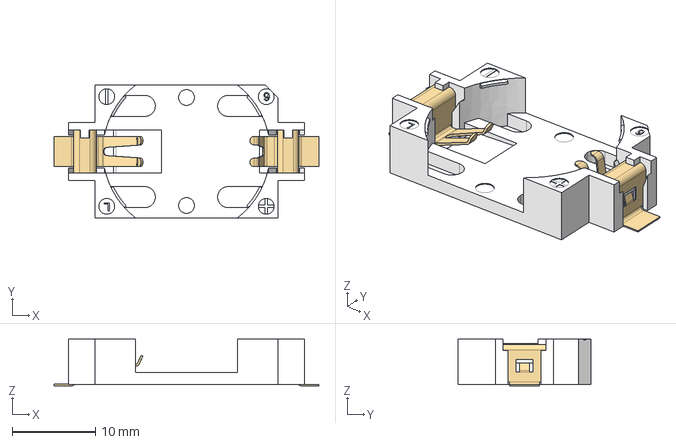
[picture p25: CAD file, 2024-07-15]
HARDWARE/KICAD/3D/WE 79527141 CR2032 SOCKET.igs
31.9 x 16.0 x 5.65 mm

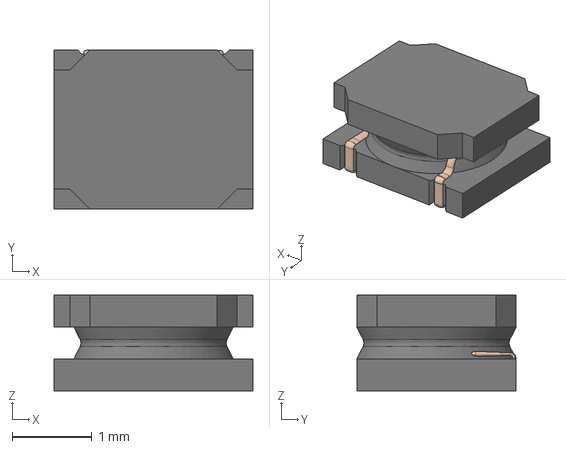
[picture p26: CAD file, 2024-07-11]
HARDWARE/KICAD/3D/WE-LQS_252012 (rev1).igs
2.50 x 2.00 x 1.20 mm

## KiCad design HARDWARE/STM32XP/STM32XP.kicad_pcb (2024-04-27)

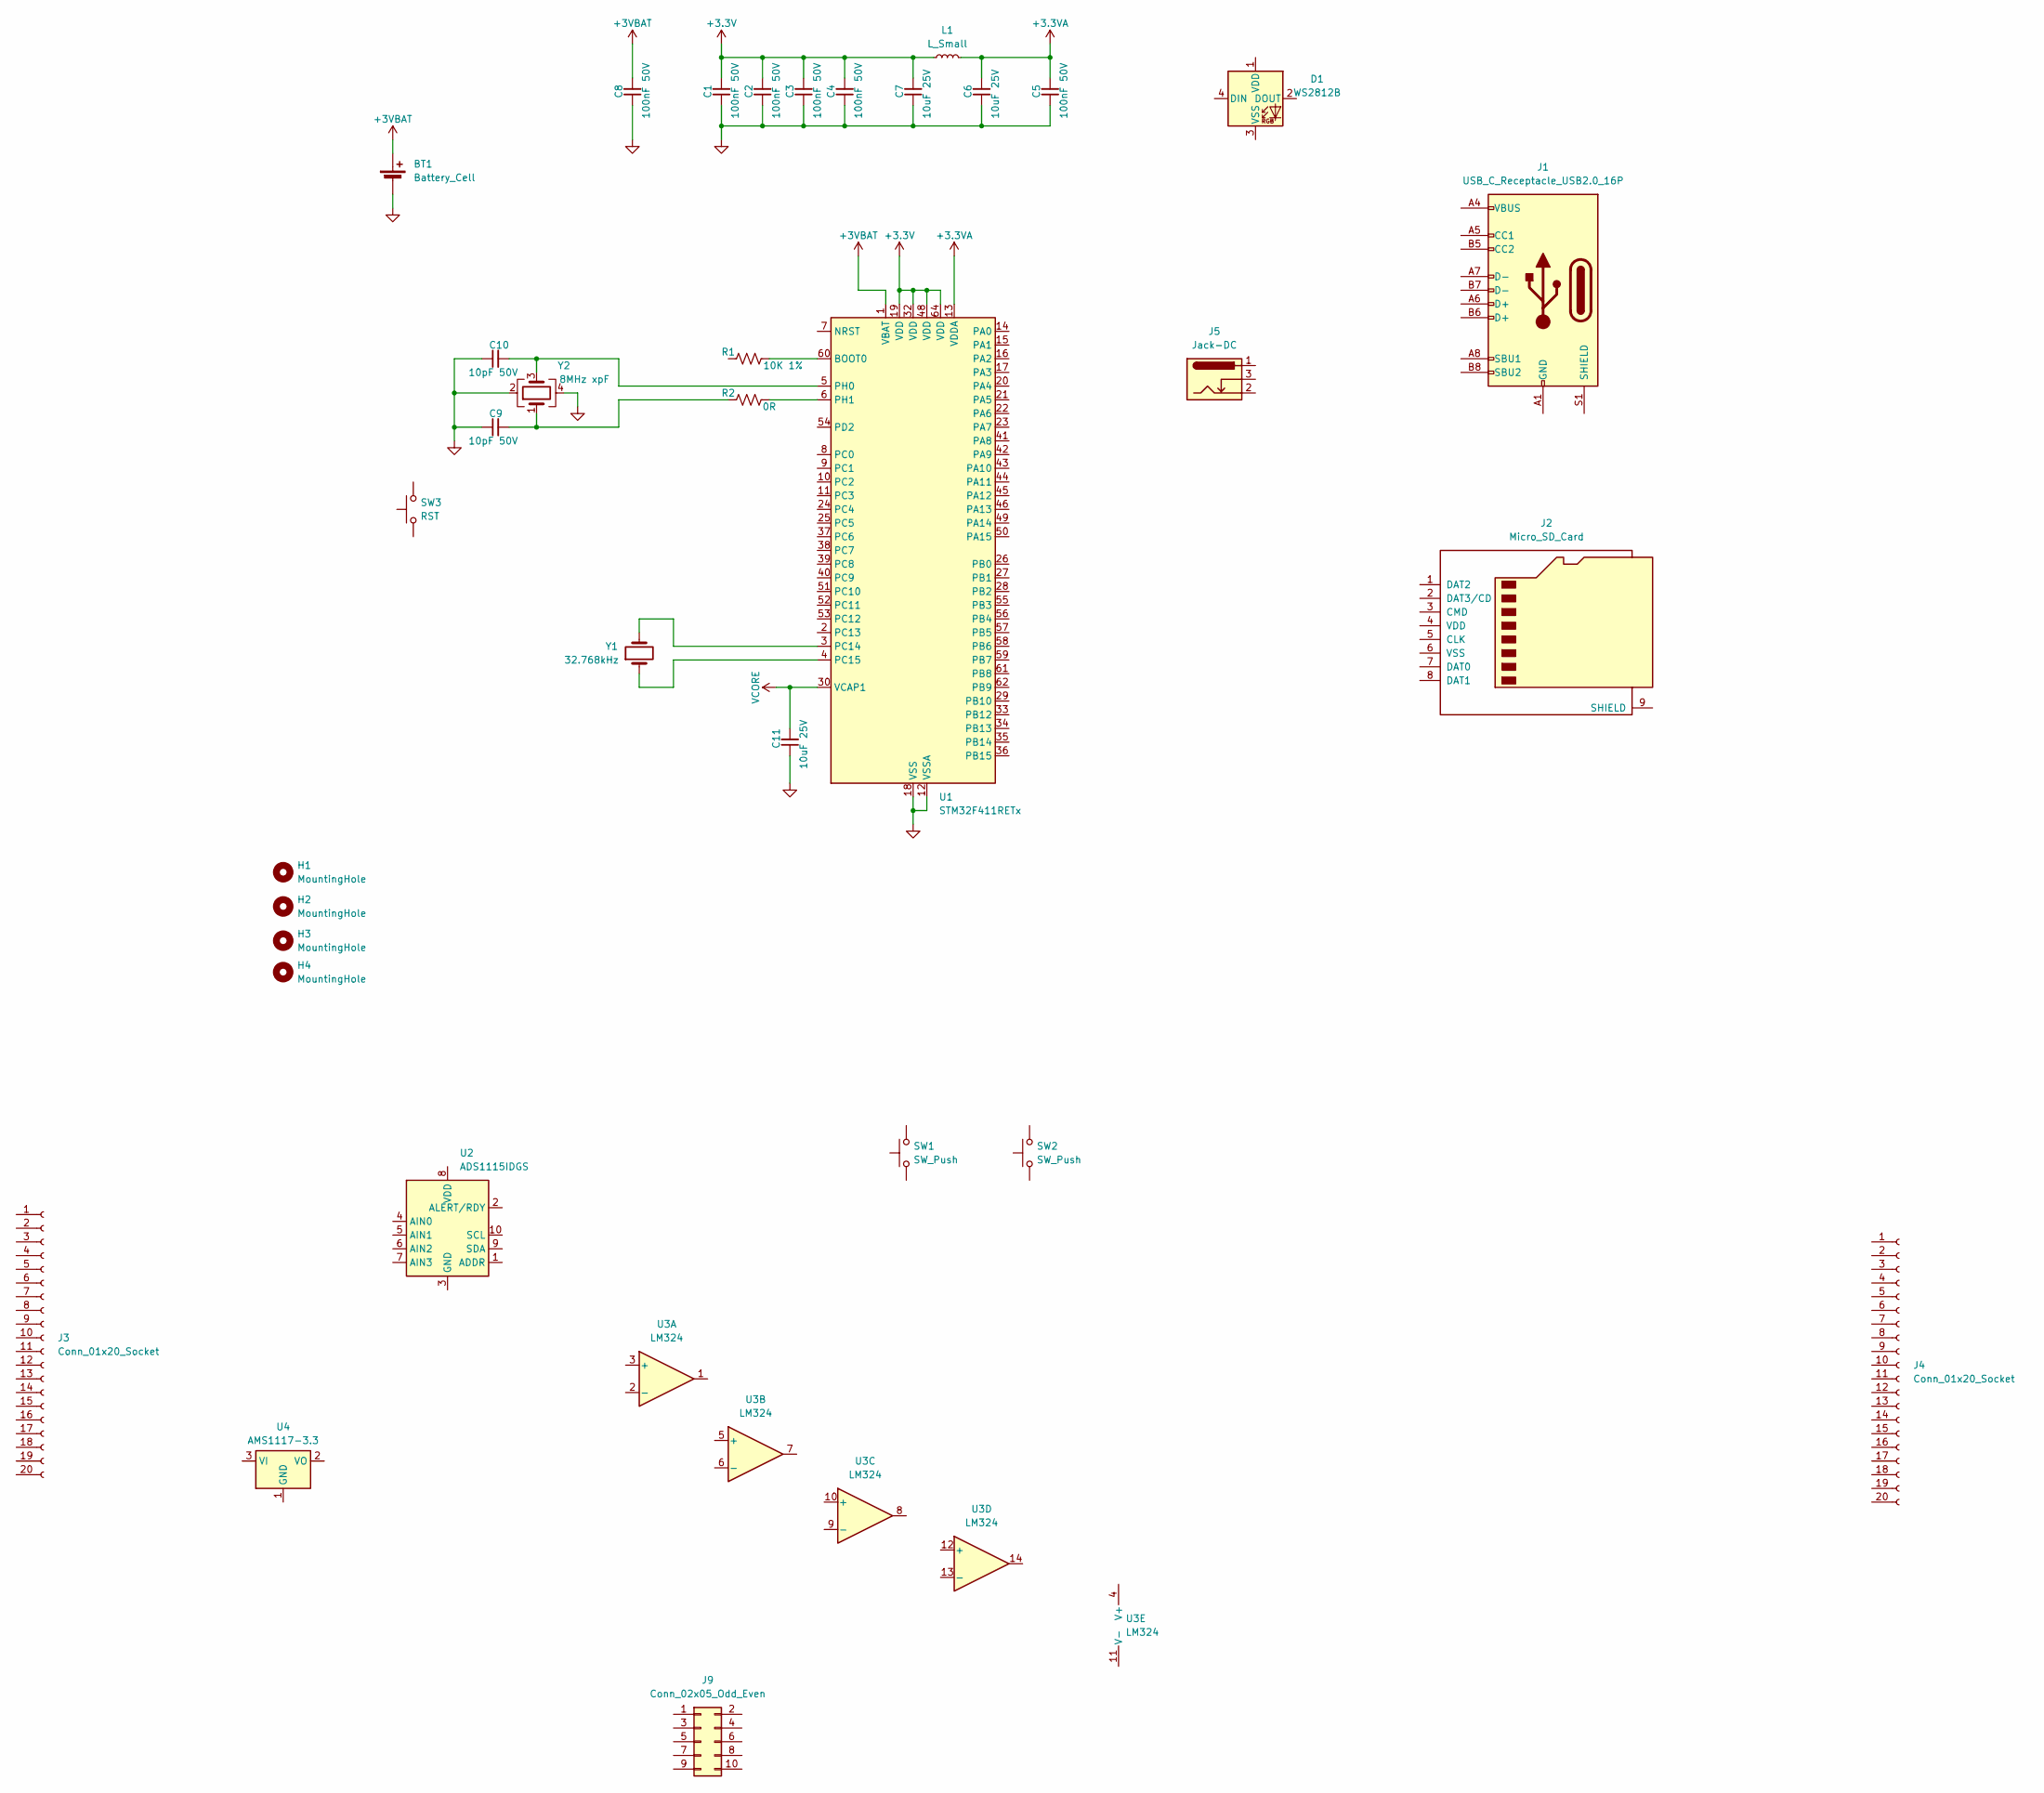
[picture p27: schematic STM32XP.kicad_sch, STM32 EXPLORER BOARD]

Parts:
BT1: Battery_Cell; BatteryHolder_Multicomp_BC-2001_1x2032
C1, C2, C3, C4, C5, C8: 100nF 50V; C_0603_1608Metric_Pad1.08x0.95mm_HandSolder
C6, C7, C11: 10uF 25V; C_0805_2012Metric_Pad1.18x1.45mm_HandSolder
C9, C10: 10pF 50V; C_0603_1608Metric_Pad1.08x0.95mm_HandSolder
D1: WS2812B; LED_WS2812B_PLCC4_5.0x5.0mm_P3.2mm
H1, H2, H3, H4: MountingHole; MountingHole_3.2mm_M3
J1: USB_C_Receptacle_USB2.0_16P; USB_C_Receptacle_G-Switch_GT-USB-7010ASV
J2: Micro_SD_Card; microSD_HC_Wuerth_693072010801
J3, J4: Conn_01x20_Socket; PinSocket_1x20_P2.54mm_Horizontal
J5: Jack-DC; BarrelJack_GCT_DCJ200-10-A_Horizontal
J9: Conn_02x05_Odd_Even; PinSocket_2x05_P2.54mm_Horizontal
L1: L_Small; L_0603_1608Metric_Pad1.05x0.95mm_HandSolder
R1: 10K 1%; R_0603_1608Metric_Pad0.98x0.95mm_HandSolder
R2: 0R; R_0603_1608Metric_Pad0.98x0.95mm_HandSolder
SW1, SW2: SW_Push; SW_SPST_CK_KXT3
SW3: RST; SW_SPST_CK_KXT3
U1: STM32F411RETx; LQFP-64_10x10mm_P0.5mm
U2: ADS1115IDGS; TSSOP-10_3x3mm_P0.5mm
U3: LM324; TSSOP-14_4.4x5mm_P0.65mm
U4: AMS1117-3.3; SOT-223-3_TabPin2
Y1: 32.768kHz; Crystal_SMD_G8-2Pin_3.2x1.5mm_HandSoldering
Y2: 8MHz xpF; Crystal_SMD_EuroQuartz_MT-4Pin_3.2x2.5mm_HandSoldering

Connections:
+3.3V: C1.2, C2.2, C3.2, C4.2, C7.2, L1.1, U1.19 (VDD), U1.32 (VDD), U1.48 (VDD), U1.64 (VDD)
+3.3VA: C5.2, C6.2, L1.2, U1.13 (VDDA)
+3VBAT: BT1.1 (+), C8.2, U1.1 (VBAT)
GND: BT1.2 (-), C1.1, C2.1, C3.1, C4.1, C5.1, C6.1, C7.1, C8.1, C9.1, C10.1, C11.1, U1.12 (VSSA), U1.18 (VSS), U1.31 (VSS), U1.47 (VSS), U1.63 (VSS), Y2.2, Y2.4
unnamed: C9.2, R2.1, Y2.1
unnamed: J1.A1 (GND), J1.A12 (GND), J1.B1 (GND), J1.B12 (GND)
unnamed: J1.A4 (VBUS), J1.A9 (VBUS), J1.B4 (VBUS), J1.B9 (VBUS)
unnamed: R1.2, U1.60 (BOOT0)
unnamed: U1.3 (PC14), Y1.2
unnamed: U1.4 (PC15), Y1.1
unnamed: C10.2, U1.5 (PH0), Y2.3
unnamed: R2.2, U1.6 (PH1)
VCORE: C11.2, U1.30 (VCAP1)

Board: 2 copper layers, 34 parts (1 on the bottom side), 13 nets, no tracks yet.

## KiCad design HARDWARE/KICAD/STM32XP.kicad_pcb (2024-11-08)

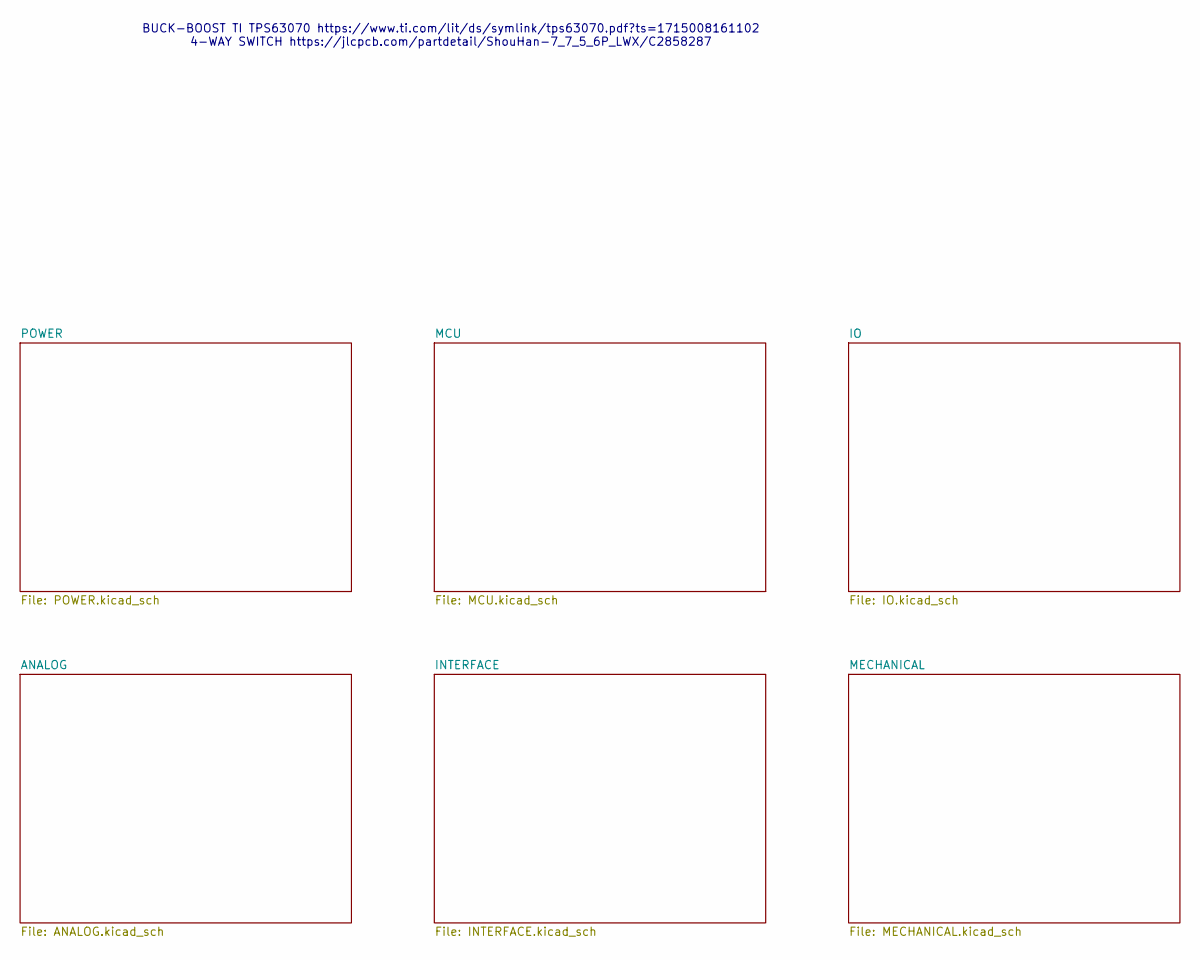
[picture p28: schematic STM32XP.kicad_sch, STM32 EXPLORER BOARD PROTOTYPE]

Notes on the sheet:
BUCK-BOOST TI TPS63070 https://www.ti.com/lit/ds/symlink/tps63070.pdf?ts=1715008161102 4-WAY SWITCH https://jlcpcb.com/partdetail/ShouHan-7_7_5_6P_LWX/C2858287

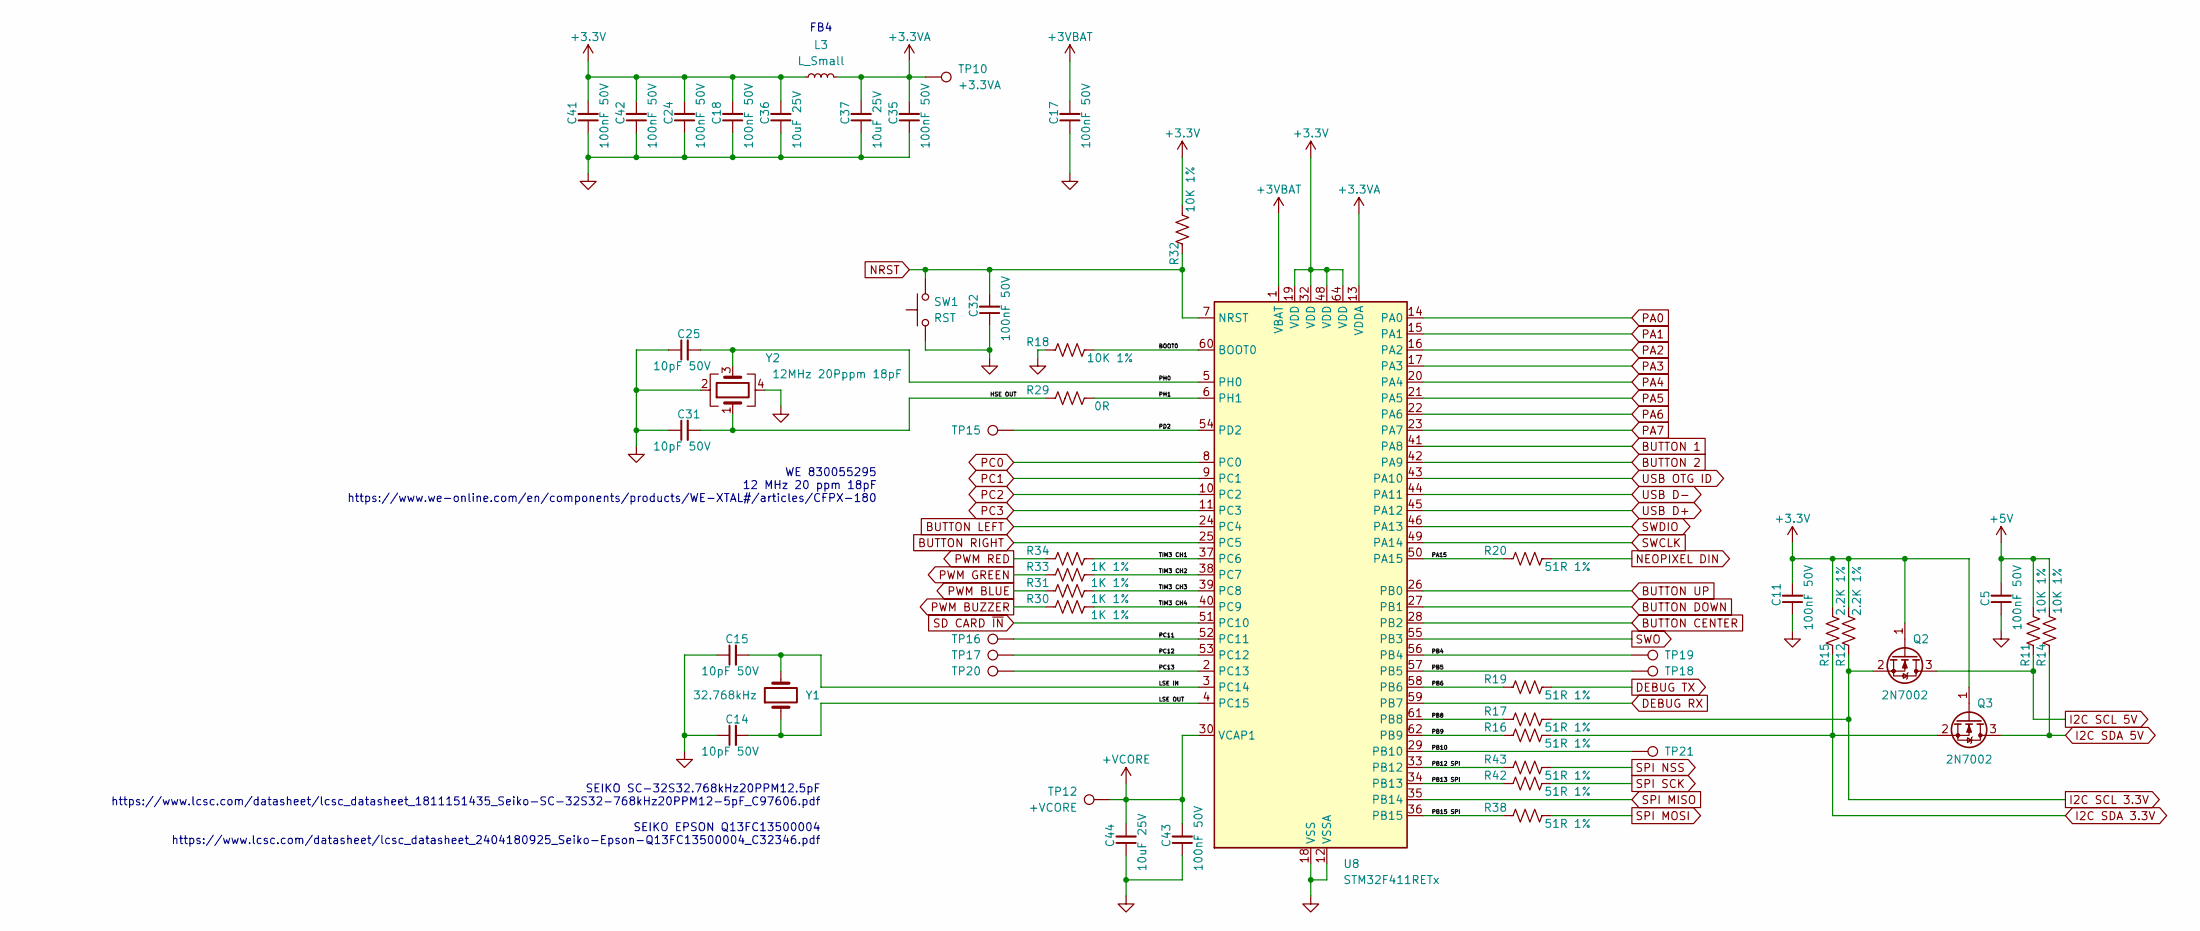
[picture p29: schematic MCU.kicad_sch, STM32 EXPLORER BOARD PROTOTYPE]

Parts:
C5, C11, C17, C18, C24, C32, C35, C41, C42, C43: 100nF 50V; C_0603_1608Metric_Pad1.08x0.95mm_HandSolder
C14, C15, C25, C31: 10pF 50V; C_0603_1608Metric_Pad1.08x0.95mm_HandSolder
C36, C37, C44: 10uF 25V; C_0805_2012Metric_Pad1.18x1.45mm_HandSolder
L3: L_Small; L_0603_1608Metric_Pad1.05x0.95mm_HandSolder
Q2, Q3: 2N7002; SOT-23
R11, R14, R18, R32: 10K 1%; R_0603_1608Metric_Pad0.98x0.95mm_HandSolder
R12, R15: 2.2K 1%; R_0603_1608Metric_Pad0.98x0.95mm_HandSolder
R16, R17, R19, R20, R38, R42, R43: 51R 1%; R_0603_1608Metric_Pad0.98x0.95mm_HandSolder
R29: 0R; R_0603_1608Metric_Pad0.98x0.95mm_HandSolder
R30, R31, R33, R34: 1K 1%; R_0603_1608Metric_Pad0.98x0.95mm_HandSolder
SW1: RST; SW_Push_1P1T_NO_CK_KSC6xxJ
TP10: +3.3VA; TestPoint_Keystone_5000-5004_Miniature
TP12: +VCORE; TestPoint_Keystone_5000-5004_Miniature
TP15: PD2; TestPoint_THTPad_D1.0mm_Drill0.5mm
TP16: PC11; TestPoint_THTPad_D1.0mm_Drill0.5mm
TP17: PC12; TestPoint_THTPad_D1.0mm_Drill0.5mm
TP18: PB5; TestPoint_THTPad_D1.0mm_Drill0.5mm
TP19: PB4; TestPoint_THTPad_D1.0mm_Drill0.5mm
TP20: PC13; TestPoint_THTPad_D1.0mm_Drill0.5mm
TP21: PB10; TestPoint_THTPad_D1.0mm_Drill0.5mm
U8: STM32F411RETx; LQFP-64_10x10mm_P0.5mm
Y1: 32.768kHz; Crystal_SMD_G8-2Pin_3.2x1.5mm_HandSoldering
Y2: 12MHz 20Pppm 18pF; Crystal_SMD_EuroQuartz_MT-4Pin_3.2x2.5mm_HandSoldering

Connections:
+3.3V: C11.2, C18.2, C24.2, C36.2, C41.2, C42.2, L3.1, Q2.1 (G), Q3.1 (G), R12.2, R15.2, R32.2, U8.19 (VDD), U8.32 (VDD), U8.48 (VDD), U8.64 (VDD); also elsewhere on the board
+3.3VA: C35.2, C37.2, L3.2, TP10.1, U8.13 (VDDA)
+3VBAT: C17.2, U8.1 (VBAT); also elsewhere on the board
+5V: C5.2, R11.2, R14.2; also elsewhere on the board
+VCORE: C43.2, C44.2, TP12.1, U8.30 (VCAP1)
/MCU/BOOT0: R18.2, U8.60 (BOOT0)
/MCU/HSE OUT: C31.2, R29.1, Y2.1
/MCU/LSE IN: C15.2, U8.3 (PC14), Y1.2
/MCU/LSE OUT: C14.2, U8.4 (PC15), Y1.1
/MCU/PA15: R20.1, U8.50 (PA15)
/MCU/PB4: TP19.1, U8.56 (PB4)
/MCU/PB5: TP18.1, U8.57 (PB5)
/MCU/PB6: R19.1, U8.58 (PB6)
/MCU/PB8: R17.1, U8.61 (PB8)
/MCU/PB9: R16.1, U8.62 (PB9)
/MCU/PB10: TP21.1, U8.29 (PB10)
/MCU/PB12 SPI: R43.1, U8.33 (PB12)
/MCU/PB13 SPI: R42.1, U8.34 (PB13)
/MCU/PB15 SPI: R38.1, U8.36 (PB15)
/MCU/PC11: TP16.1, U8.52 (PC11)
/MCU/PC12: TP17.1, U8.53 (PC12)
/MCU/PC13: TP20.1, U8.2 (PC13)
/MCU/PD2: TP15.1, U8.54 (PD2)
/MCU/PH0: C25.2, U8.5 (PH0), Y2.3
/MCU/PH1: R29.2, U8.6 (PH1)
/MCU/TIM3 CH1: R34.2, U8.37 (PC6)
/MCU/TIM3 CH2: R33.2, U8.38 (PC7)
/MCU/TIM3 CH3: R31.2, U8.39 (PC8)
/MCU/TIM3 CH4: R30.2, U8.40 (PC9)
BUTTON 1: U8.41 (PA8); also elsewhere on the board
BUTTON 2: U8.42 (PA9); also elsewhere on the board
BUTTON CENTER: U8.28 (PB2); also elsewhere on the board
BUTTON DOWN: U8.27 (PB1); also elsewhere on the board
BUTTON LEFT: U8.24 (PC4); also elsewhere on the board
BUTTON RIGHT: U8.25 (PC5); also elsewhere on the board
BUTTON UP: U8.26 (PB0); also elsewhere on the board
DEBUG RX: U8.59 (PB7); also elsewhere on the board
DEBUG TX: R19.2; also elsewhere on the board
GND: C5.1, C11.1, C14.1, C15.1, C17.1, C18.1, C24.1, C25.1, C31.1, C32.1, C35.1, C36.1, C37.1, C41.1, C42.1, C43.1, C44.1, R18.1, SW1.1, U8.12 (VSSA), U8.18 (VSS), U8.31 (VSS), U8.47 (VSS), U8.63 (VSS), Y2.2, Y2.4; also elsewhere on the board
I2C SCL 3.3V: Q2.2 (S), R12.1, R17.2; also elsewhere on the board
I2C SCL 5V: Q2.3 (D), R11.1; also elsewhere on the board
I2C SDA 3.3V: Q3.2 (S), R15.1, R16.2; also elsewhere on the board
I2C SDA 5V: Q3.3 (D), R14.1; also elsewhere on the board
NEOPIXEL DIN: R20.2; also elsewhere on the board
NRST: C32.2, R32.1, SW1.2, U8.7 (NRST); also elsewhere on the board
PA0: U8.14 (PA0); also elsewhere on the board
PA1: U8.15 (PA1); also elsewhere on the board
PA2: U8.16 (PA2); also elsewhere on the board
PA3: U8.17 (PA3); also elsewhere on the board
PA4: U8.20 (PA4); also elsewhere on the board
PA5: U8.21 (PA5); also elsewhere on the board
PA6: U8.22 (PA6); also elsewhere on the board
PA7: U8.23 (PA7); also elsewhere on the board
PC0: U8.8 (PC0); also elsewhere on the board
PC1: U8.9 (PC1); also elsewhere on the board
PC2: U8.10 (PC2); also elsewhere on the board
PC3: U8.11 (PC3); also elsewhere on the board
PWM BLUE: R31.1; also elsewhere on the board
PWM BUZZER: R30.1; also elsewhere on the board
PWM GREEN: R33.1; also elsewhere on the board
PWM RED: R34.1; also elsewhere on the board
SD CARD ~IN: U8.51 (PC10); also elsewhere on the board
SPI MISO: U8.35 (PB14); also elsewhere on the board
SPI MOSI: R38.2; also elsewhere on the board
SPI NSS: R43.2; also elsewhere on the board
SPI SCK: R42.2; also elsewhere on the board
SWCLK: U8.49 (PA14); also elsewhere on the board
SWDIO: U8.46 (PA13); also elsewhere on the board
SWO: U8.55 (PB3); also elsewhere on the board
USB D+: U8.45 (PA12); also elsewhere on the board
USB D-: U8.44 (PA11); also elsewhere on the board
USB OTG ID: U8.43 (PA10); also elsewhere on the board

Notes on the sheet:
FB4
WE 830055295 12 MHz 20 ppm 18pF https://www.we-online.com/en/components/products/WE-XTAL#/articles/CFPX-180
SEIKO SC-32S32.768kHz20PPM12.5pF https://www.lcsc.com/datasheet/lcsc_datasheet_1811151435_Seiko-SC-32S32-768kHz20PPM12-5pF_C97606.pdf SEIKO EPSON Q13FC13500004 https://www.lcsc.com/datasheet/lcsc_datasheet_2404180925_Seiko-Epson-Q13FC13500004_C32346.pdf

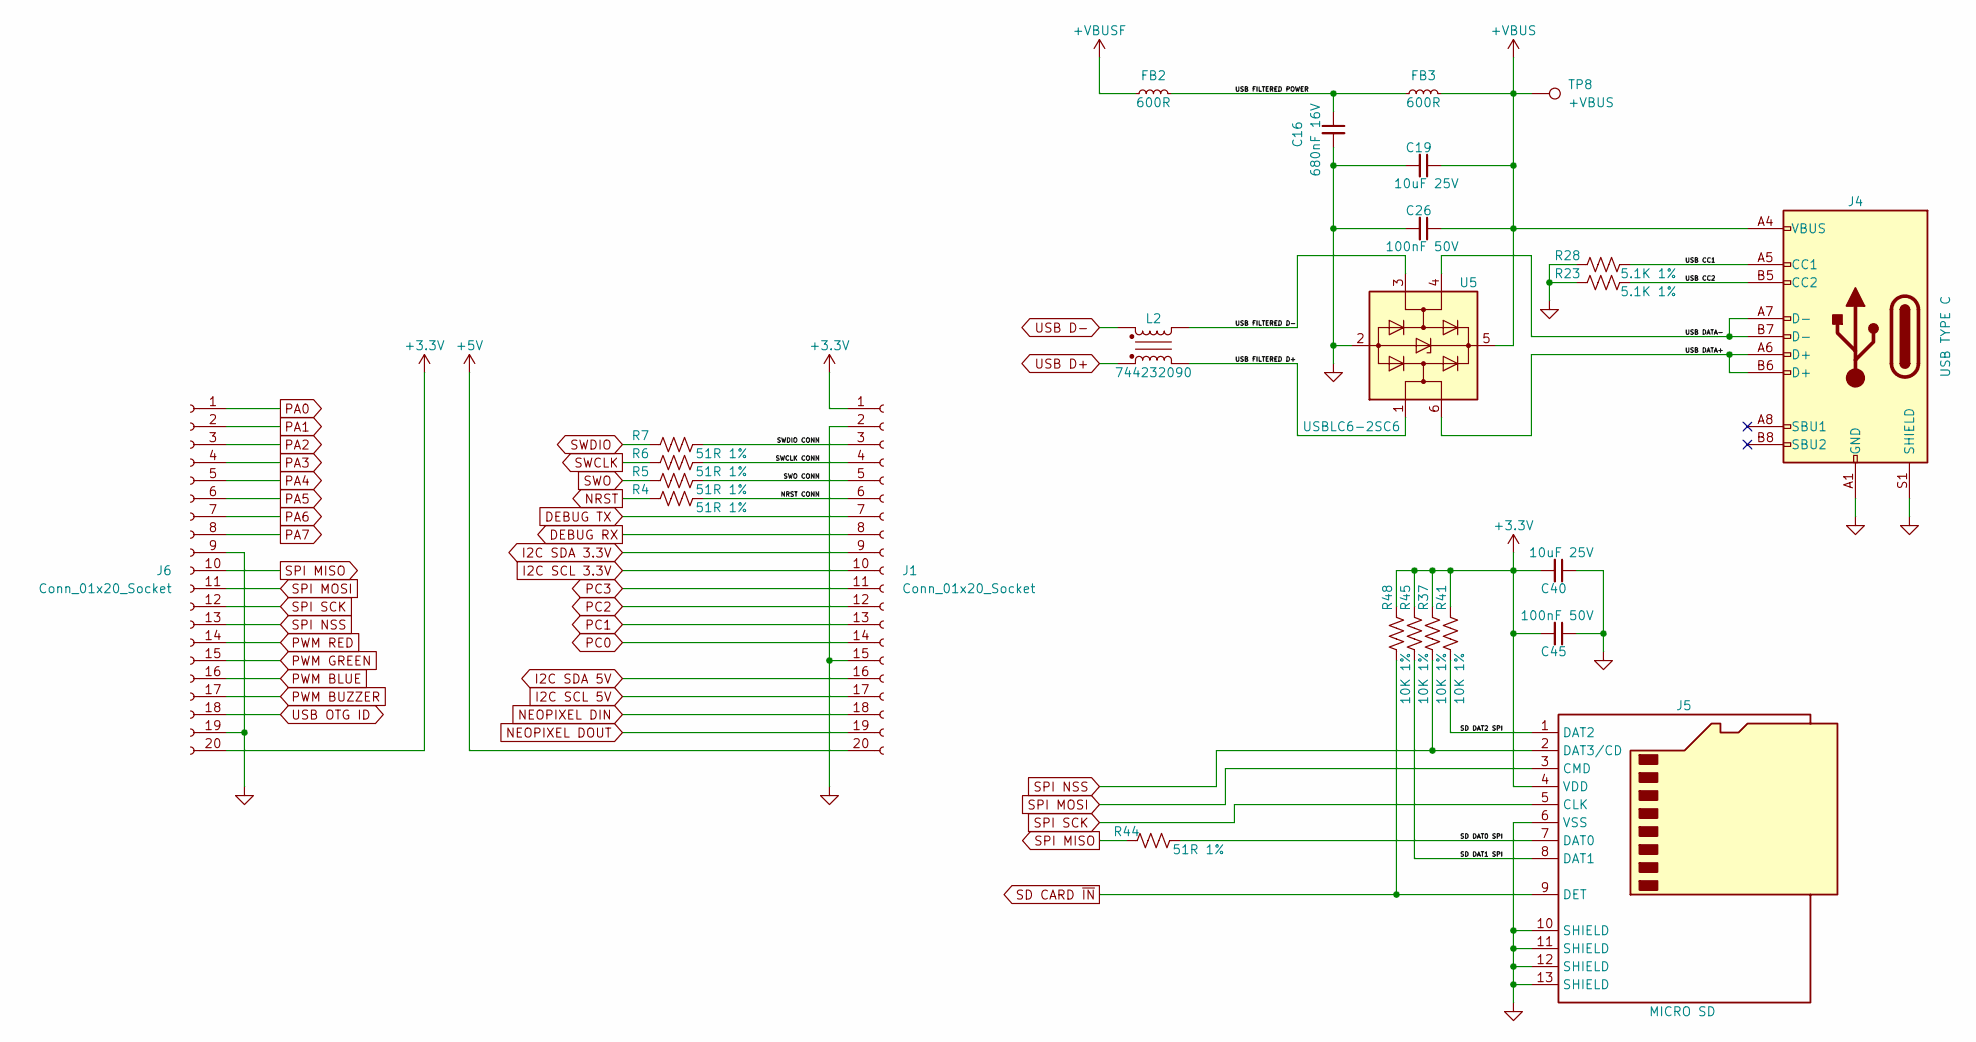
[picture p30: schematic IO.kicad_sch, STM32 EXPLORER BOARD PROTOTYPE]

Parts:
C16: 680nF 16V; C_0603_1608Metric_Pad1.08x0.95mm_HandSolder
C19, C40: 10uF 25V; C_0805_2012Metric_Pad1.18x1.45mm_HandSolder
C26, C45: 100nF 50V; C_0603_1608Metric_Pad1.08x0.95mm_HandSolder
FB2, FB3: 600R; L_0603_1608Metric_Pad1.05x0.95mm_HandSolder
J1, J6: Conn_01x20_Socket; PinSocket_1x20_P2.54mm_Horizontal
J4: USB TYPE C; USB_C_Receptacle_G-Switch_GT-USB-7010ASV
J5: MICRO SD; WE 693071020811
L2: 744232090; WE 744232090
R4, R5, R6, R7, R44: 51R 1%; R_0603_1608Metric_Pad0.98x0.95mm_HandSolder
R23, R28: 5.1K 1%; R_0603_1608Metric_Pad0.98x0.95mm_HandSolder
R37, R41, R45, R48: 10K 1%; R_0603_1608Metric_Pad0.98x0.95mm_HandSolder
TP8: +VBUS; TestPoint_Keystone_5000-5004_Miniature
U5: USBLC6-2SC6; SOT-23-6

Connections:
+3.3V: C40.2, C45.2, J1.1, J5.4 (VDD), J6.20, R37.2, R41.2, R45.2, R48.2; also elsewhere on the board
+5V: J1.20; also elsewhere on the board
+VBUS: C19.1, C26.1, FB3.2, J4.A4 (VBUS), J4.A9 (VBUS), J4.B4 (VBUS), J4.B9 (VBUS), TP8.1, U5.5 (VBUS)
+VBUSF: FB2.1; also elsewhere on the board
/IO/NRST CONN: J1.6, R4.2
/IO/SD DAT0 SPI: J5.7 (DAT0), R44.2
/IO/SD DAT1 SPI: J5.8 (DAT1), R45.1
/IO/SD DAT2 SPI: J5.1 (DAT2), R41.1
/IO/SWCLK CONN: J1.4, R6.2
/IO/SWDIO CONN: J1.3, R7.2
/IO/SWO CONN: J1.5, R5.2
/IO/USB CC1: J4.A5 (CC1), R28.2
/IO/USB CC2: J4.B5 (CC2), R23.2
/IO/USB DATA+: J4.A6 (D+), J4.B6 (D+), U5.6 (I/O1)
/IO/USB DATA-: J4.A7 (D-), J4.B7 (D-), U5.4 (I/O2)
/IO/USB FILTERED D+: L2.3, U5.1 (I/O1)
/IO/USB FILTERED D-: L2.2, U5.3 (I/O2)
/IO/USB FILTERED POWER: C16.1, FB2.2, FB3.1
DEBUG RX: J1.8; also elsewhere on the board
DEBUG TX: J1.7; also elsewhere on the board
GND: C16.2, C19.2, C26.2, C40.1, C45.1, J1.2, J1.15, J4.A1 (GND), J4.A12 (GND), J4.B1 (GND), J4.B12 (GND), J4.S1 (SHIELD), J5.6 (VSS), J5.10 (SHIELD), J5.11 (SHIELD), J5.12 (SHIELD), J5.13 (SHIELD), J6.9, J6.19, R23.1, R28.1, U5.2 (GND); also elsewhere on the board
I2C SCL 3.3V: J1.10; also elsewhere on the board
I2C SCL 5V: J1.17; also elsewhere on the board
I2C SDA 3.3V: J1.9; also elsewhere on the board
I2C SDA 5V: J1.16; also elsewhere on the board
NEOPIXEL DIN: J1.18; also elsewhere on the board
NEOPIXEL DOUT: J1.19; also elsewhere on the board
NRST: R4.1; also elsewhere on the board
PA0: J6.1; also elsewhere on the board
PA1: J6.2; also elsewhere on the board
PA2: J6.3; also elsewhere on the board
PA3: J6.4; also elsewhere on the board
PA4: J6.5; also elsewhere on the board
PA5: J6.6; also elsewhere on the board
PA6: J6.7; also elsewhere on the board
PA7: J6.8; also elsewhere on the board
PC0: J1.14; also elsewhere on the board
PC1: J1.13; also elsewhere on the board
PC2: J1.12; also elsewhere on the board
PC3: J1.11; also elsewhere on the board
PWM BLUE: J6.16; also elsewhere on the board
PWM BUZZER: J6.17; also elsewhere on the board
PWM GREEN: J6.15; also elsewhere on the board
PWM RED: J6.14; also elsewhere on the board
SD CARD ~IN: J5.9 (DET), R48.1; also elsewhere on the board
SPI MISO: J6.10, R44.1; also elsewhere on the board
SPI MOSI: J5.3 (CMD), J6.11; also elsewhere on the board
SPI NSS: J5.2 (DAT3/CD), J6.13, R37.1; also elsewhere on the board
SPI SCK: J5.5 (CLK), J6.12; also elsewhere on the board
SWCLK: R6.1; also elsewhere on the board
SWDIO: R7.1; also elsewhere on the board
SWO: R5.1; also elsewhere on the board
USB D+: L2.4; also elsewhere on the board
USB D-: L2.1; also elsewhere on the board
USB OTG ID: J6.18; also elsewhere on the board

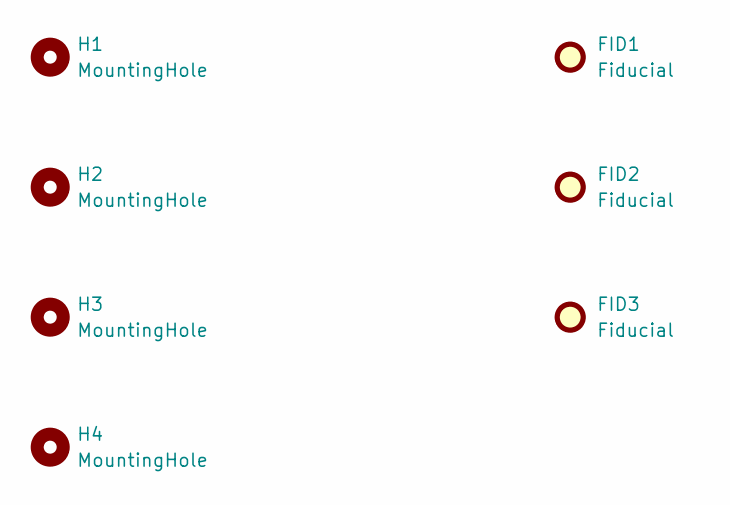
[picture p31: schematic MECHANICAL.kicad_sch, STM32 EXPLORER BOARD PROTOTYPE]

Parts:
FID1, FID2, FID3: Fiducial; Fiducial_0.75mm_Mask1.5mm
H1, H2, H3, H4: MountingHole; MountingHole_3.2mm_M3

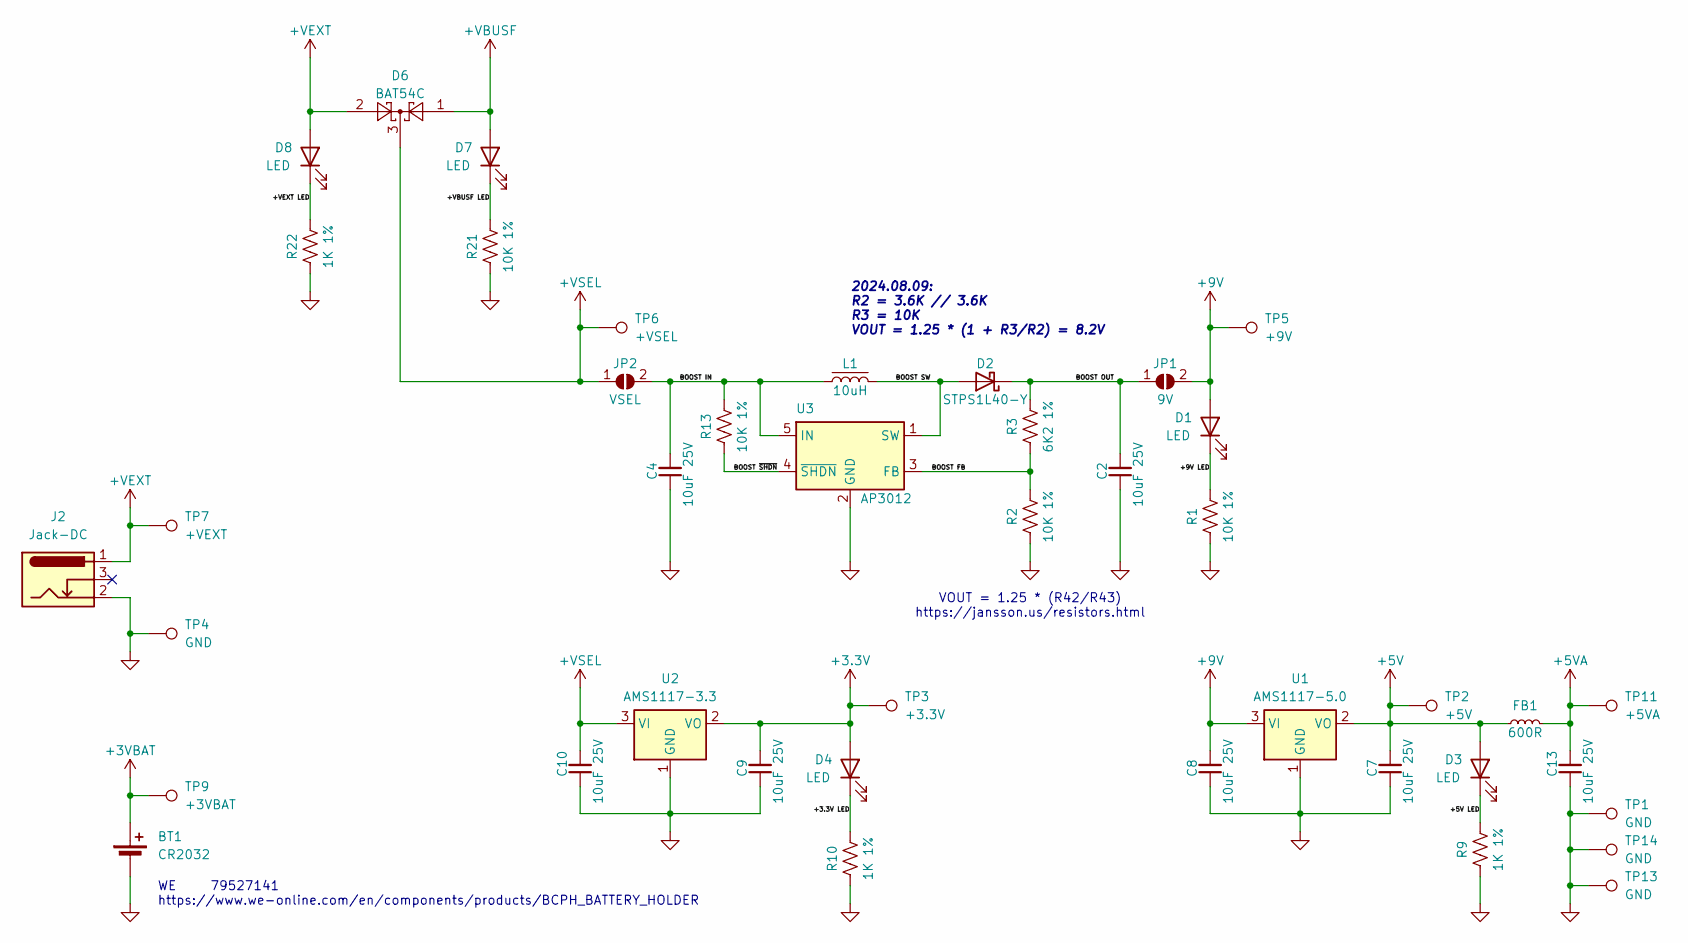
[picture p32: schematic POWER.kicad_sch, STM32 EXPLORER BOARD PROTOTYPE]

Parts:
BT1: CR2032; BatteryHolder_Keystone_1060_1x2032
C2, C4, C7, C8, C9, C10, C13: 10uF 25V; C_0805_2012Metric_Pad1.18x1.45mm_HandSolder
D1, D3, D4, D7, D8: LED; LED_0603_1608Metric_Pad1.05x0.95mm_HandSolder
D2: STPS1L40-Y; D_SOD-123
D6: BAT54C; SOT-23
FB1: 600R; L_0603_1608Metric_Pad1.05x0.95mm_HandSolder
J2: Jack-DC; BarrelJack_GCT_DCJ200-10-A_Horizontal
JP1: 9V; SolderJumper-2_P1.3mm_Open_RoundedPad1.0x1.5mm
JP2: VSEL; SolderJumper-2_P1.3mm_Open_RoundedPad1.0x1.5mm
L1: 10uH; WE 74404024100
R1, R2, R13, R21: 10K 1%; R_0603_1608Metric_Pad0.98x0.95mm_HandSolder
R3: 6K2 1%; R_0603_1608Metric_Pad0.98x0.95mm_HandSolder
R9, R10, R22: 1K 1%; R_0603_1608Metric_Pad0.98x0.95mm_HandSolder
TP1, TP4, TP13, TP14: GND; TestPoint_Keystone_5000-5004_Miniature
TP2: +5V; TestPoint_Keystone_5000-5004_Miniature
TP3: +3.3V; TestPoint_Keystone_5000-5004_Miniature
TP5: +9V; TestPoint_Keystone_5000-5004_Miniature
TP6: +VSEL; TestPoint_Keystone_5000-5004_Miniature
TP7: +VEXT; TestPoint_Keystone_5000-5004_Miniature
TP9: +3VBAT; TestPoint_Keystone_5000-5004_Miniature
TP11: +5VA; TestPoint_Keystone_5000-5004_Miniature
U1: AMS1117-5.0; SOT-223-3_TabPin2
U2: AMS1117-3.3; SOT-223-3_TabPin2
U3: AP3012; SOT-23-5

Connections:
+3.3V: C9.2, D4.2 (A), TP3.1, U2.2 (VO); also elsewhere on the board
+3VBAT: BT1.1 (+), TP9.1; also elsewhere on the board
+5V: C7.2, D3.2 (A), FB1.1, TP2.1, U1.2 (VO); also elsewhere on the board
+5VA: C13.2, FB1.2, TP11.1; also elsewhere on the board
+9V: C8.2, D1.2 (A), JP1.2 (B), TP5.1, U1.3 (VI); also elsewhere on the board
+VBUSF: D6.1, D7.2 (A); also elsewhere on the board
+VEXT: D6.2, D8.2 (A), J2.1, TP7.1
+VSEL: C10.2, D6.3, JP2.1 (A), TP6.1, U2.3 (VI)
/POWER/+3.3V LED: D4.1 (K), R10.2
/POWER/+5V LED: D3.1 (K), R9.2
/POWER/+9V LED: D1.1 (K), R1.2
/POWER/+VBUSF LED: D7.1 (K), R21.2
/POWER/+VEXT LED: D8.1 (K), R22.2
/POWER/BOOST FB: R2.2, R3.1, U3.3 (FB)
/POWER/BOOST IN: C4.2, JP2.2 (B), L1.1, R13.2, U3.5 (IN)
/POWER/BOOST OUT: C2.2, D2.1 (K), JP1.1 (A), R3.2
/POWER/BOOST SW: D2.2 (A), L1.2, U3.1 (SW)
/POWER/BOOST ~SHDN: R13.1, U3.4 (~SHDN)
GND: BT1.2 (-), C2.1, C4.1, C7.1, C8.1, C9.1, C10.1, C13.1, J2.2, R1.1, R2.1, R9.1, R10.1, R21.1, R22.1, TP1.1, TP4.1, TP13.1, TP14.1, U1.1 (GND), U2.1 (GND), U3.2 (GND); also elsewhere on the board

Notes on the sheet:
2024.08.09: R2 = 3.6K // 3.6K R3 = 10K VOUT = 1.25 * (1 + R3/R2) = 8.2V
VOUT = 1.25 * (R42/R43) https://jansson.us/resistors.html
WE 79527141 https://www.we-online.com/en/components/products/BCPH_BATTERY_HOLDER

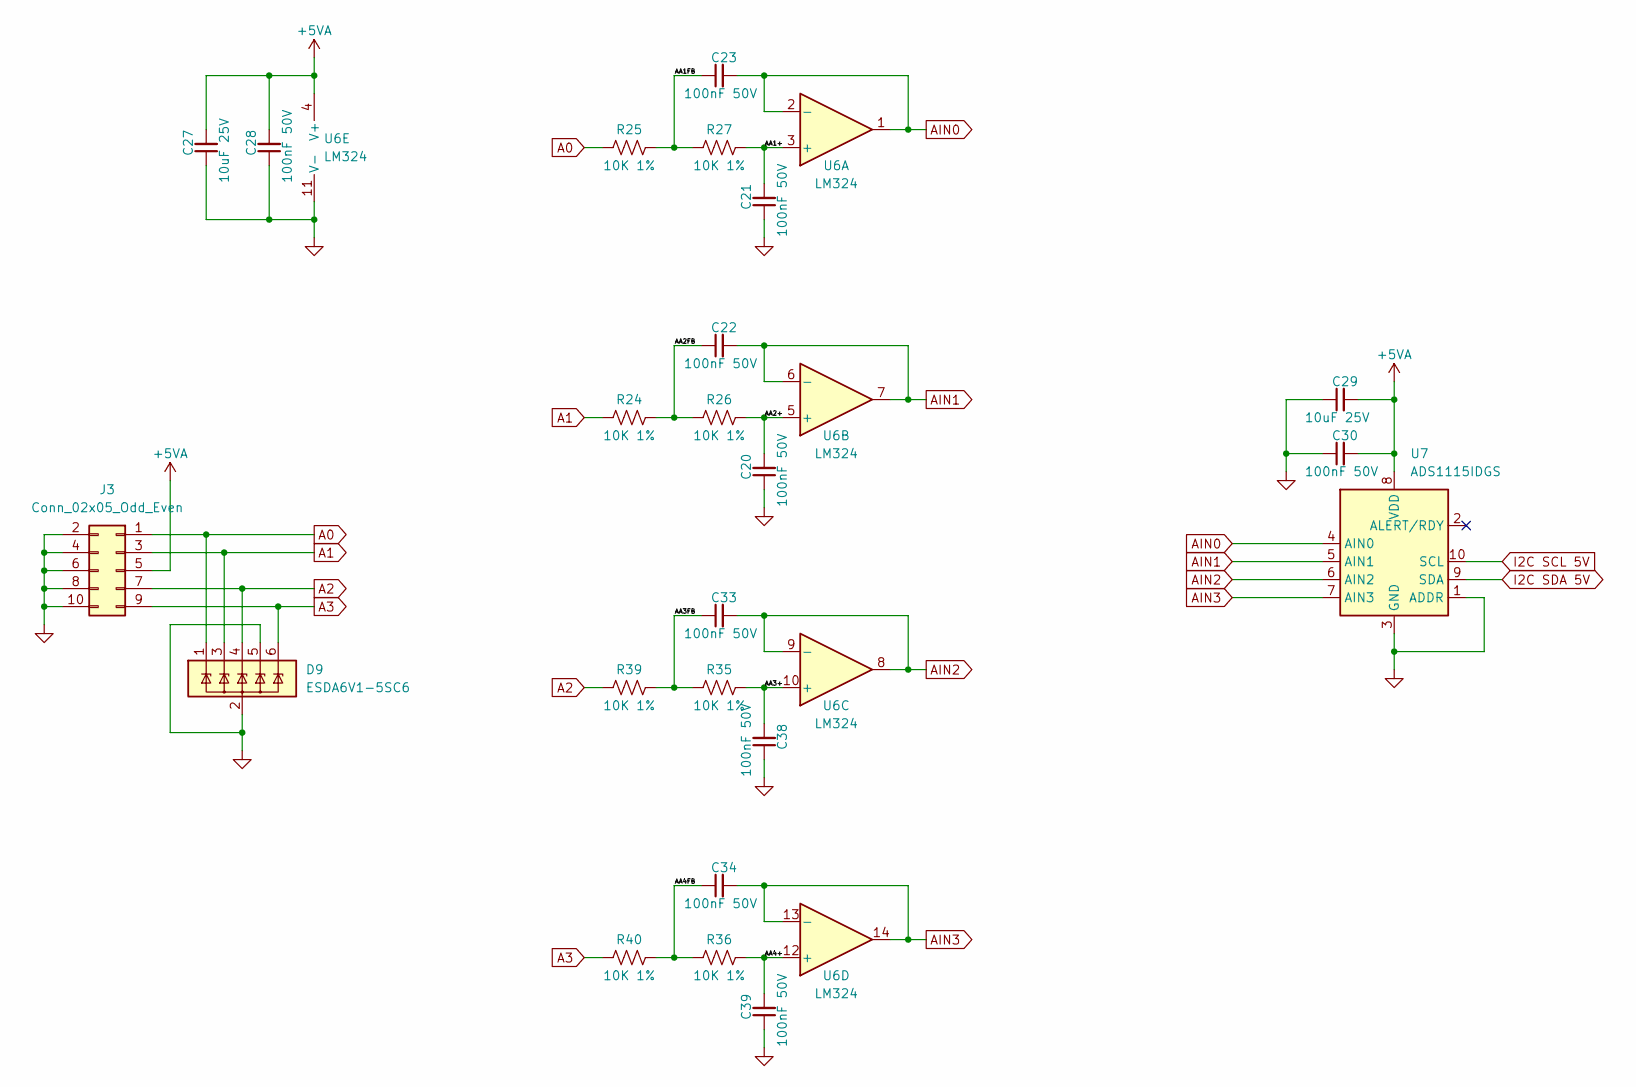
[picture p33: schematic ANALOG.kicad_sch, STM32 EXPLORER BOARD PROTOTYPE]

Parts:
C20, C21, C22, C23, C28, C30, C33, C34, C38, C39: 100nF 50V; C_0603_1608Metric_Pad1.08x0.95mm_HandSolder
C27, C29: 10uF 25V; C_0805_2012Metric_Pad1.18x1.45mm_HandSolder
D9: ESDA6V1-5SC6; SOT-23-6
J3: Conn_02x05_Odd_Even; PinSocket_2x05_P2.54mm_Horizontal
R24, R25, R26, R27, R35, R36, R39, R40: 10K 1%; R_0603_1608Metric_Pad0.98x0.95mm_HandSolder
U6: LM324; TSSOP-14_4.4x5mm_P0.65mm
U7: ADS1115IDGS; TSSOP-10_3x3mm_P0.5mm

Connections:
+5VA: C27.2, C28.2, C29.2, C30.2, J3.5, U6.4 (V+), U7.8 (VDD); also elsewhere on the board
/ANALOG/AA1+: C21.2, R27.2, U6.3 (+)
/ANALOG/AA1FB: C23.1, R25.2, R27.1
/ANALOG/AA2+: C20.2, R26.2, U6.5 (+)
/ANALOG/AA2FB: C22.1, R24.2, R26.1
/ANALOG/AA3+: C38.2, R35.2, U6.10 (+)
/ANALOG/AA3FB: C33.1, R35.1, R39.2
/ANALOG/AA4+: C39.2, R36.2, U6.12 (+)
/ANALOG/AA4FB: C34.1, R36.1, R40.2
A0: D9.1 (IO1), J3.1, R25.1
A1: D9.3 (IO2), J3.3, R24.1
A2: D9.4 (IO3), J3.7, R39.1
A3: D9.6 (IO5), J3.9, R40.1
AIN0: C23.2, U6.1, U6.2 (-), U7.4 (AIN0)
AIN1: C22.2, U6.6 (-), U6.7, U7.5 (AIN1)
AIN2: C33.2, U6.8, U6.9 (-), U7.6 (AIN2)
AIN3: C34.2, U6.13 (-), U6.14, U7.7 (AIN3)
GND: C20.1, C21.1, C27.1, C28.1, C29.1, C30.1, C38.1, C39.1, D9.2 (GND), D9.5 (IO4), J3.2, J3.4, J3.6, J3.8, J3.10, U6.11 (V-), U7.1 (ADDR), U7.3 (GND); also elsewhere on the board
I2C SCL 5V: U7.10 (SCL); also elsewhere on the board
I2C SDA 5V: U7.9 (SDA); also elsewhere on the board

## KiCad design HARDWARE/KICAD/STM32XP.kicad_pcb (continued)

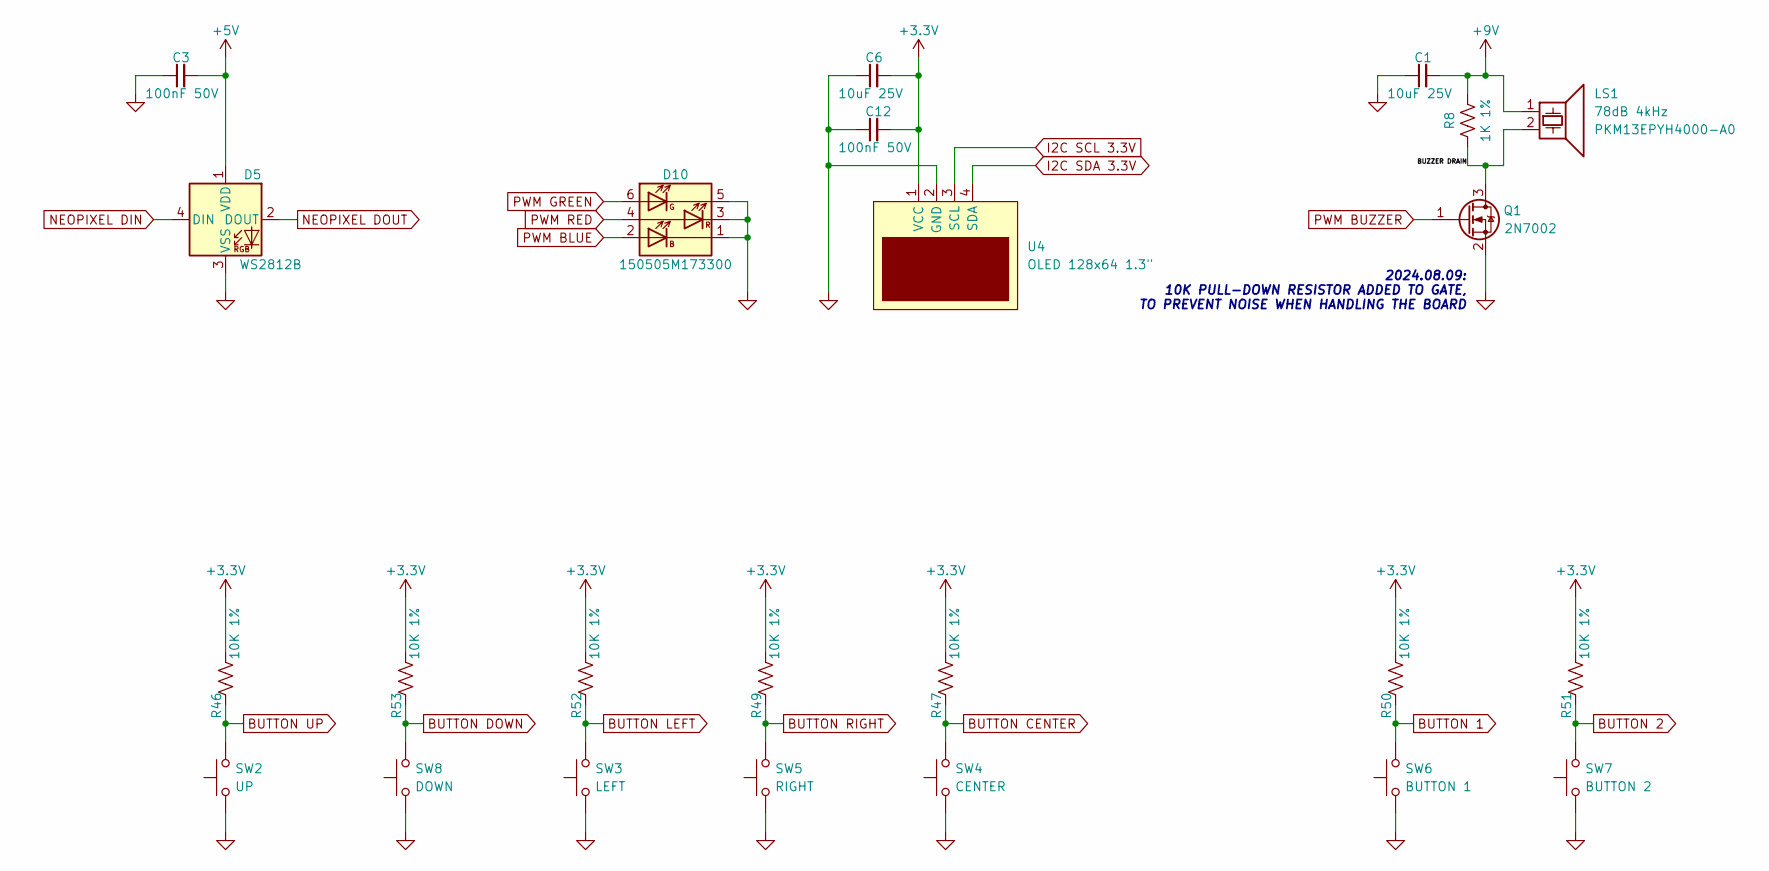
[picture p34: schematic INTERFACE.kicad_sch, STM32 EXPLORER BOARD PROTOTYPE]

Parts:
C1, C6: 10uF 25V; C_0805_2012Metric_Pad1.18x1.45mm_HandSolder
C3, C12: 100nF 50V; C_0603_1608Metric_Pad1.08x0.95mm_HandSolder
D5: WS2812B; LED_WS2812B_PLCC4_5.0x5.0mm_P3.2mm
D10: 150505M173300; WE 150505M173300
LS1: 78dB 4kHz; PKM13EPYH4000-A0
Q1: 2N7002; SOT-23
R8: 1K 1%; R_0603_1608Metric_Pad0.98x0.95mm_HandSolder
R46, R47, R49, R50, R51, R52, R53: 10K 1%; R_0603_1608Metric_Pad0.98x0.95mm_HandSolder
SW2: UP; SW_Push_1P1T_NO_CK_KSC6xxJ
SW3: LEFT; SW_Push_1P1T_NO_CK_KSC6xxJ
SW4: CENTER; SW_Push_1P1T_NO_CK_KSC6xxJ
SW5: RIGHT; SW_Push_1P1T_NO_CK_KSC6xxJ
SW6: BUTTON 1; SW_Push_1P1T_NO_CK_KSC6xxJ
SW7: BUTTON 2; SW_Push_1P1T_NO_CK_KSC6xxJ
SW8: DOWN; SW_Push_1P1T_NO_CK_KSC6xxJ
U4: OLED 128x64 1.3"; OLED 128x64 1.3in

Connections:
+3.3V: C6.2, C12.2, R46.2, R47.2, R49.2, R50.2, R51.2, R52.2, R53.2, U4.1 (VCC); also elsewhere on the board
+5V: C3.2, D5.1 (VDD); also elsewhere on the board
+9V: C1.2, LS1.1, R8.2; also elsewhere on the board
/INTERFACE/BUZZER DRAIN: LS1.2, Q1.3 (D), R8.1
BUTTON 1: R50.1, SW6.2; also elsewhere on the board
BUTTON 2: R51.1, SW7.2; also elsewhere on the board
BUTTON CENTER: R47.1, SW4.2; also elsewhere on the board
BUTTON DOWN: R53.1, SW8.2; also elsewhere on the board
BUTTON LEFT: R52.1, SW3.2; also elsewhere on the board
BUTTON RIGHT: R49.1, SW5.2; also elsewhere on the board
BUTTON UP: R46.1, SW2.2; also elsewhere on the board
GND: C1.1, C3.1, C6.1, C12.1, D5.3 (VSS), D10.1 (KB), D10.3 (KR), D10.5 (KG), Q1.2 (S), SW2.1, SW3.1, SW4.1, SW5.1, SW6.1, SW7.1, SW8.1, U4.2 (GND); also elsewhere on the board
I2C SCL 3.3V: U4.3 (SCL); also elsewhere on the board
I2C SDA 3.3V: U4.4 (SDA); also elsewhere on the board
NEOPIXEL DIN: D5.4 (DIN); also elsewhere on the board
NEOPIXEL DOUT: D5.2 (DOUT); also elsewhere on the board
PWM BLUE: D10.2 (AB); also elsewhere on the board
PWM BUZZER: Q1.1 (G); also elsewhere on the board
PWM GREEN: D10.6 (AG); also elsewhere on the board
PWM RED: D10.4 (AR); also elsewhere on the board

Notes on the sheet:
2024.08.09: 10K PULL-DOWN RESISTOR ADDED TO GATE, TO PREVENT NOISE WHEN HANDLING THE BOARD

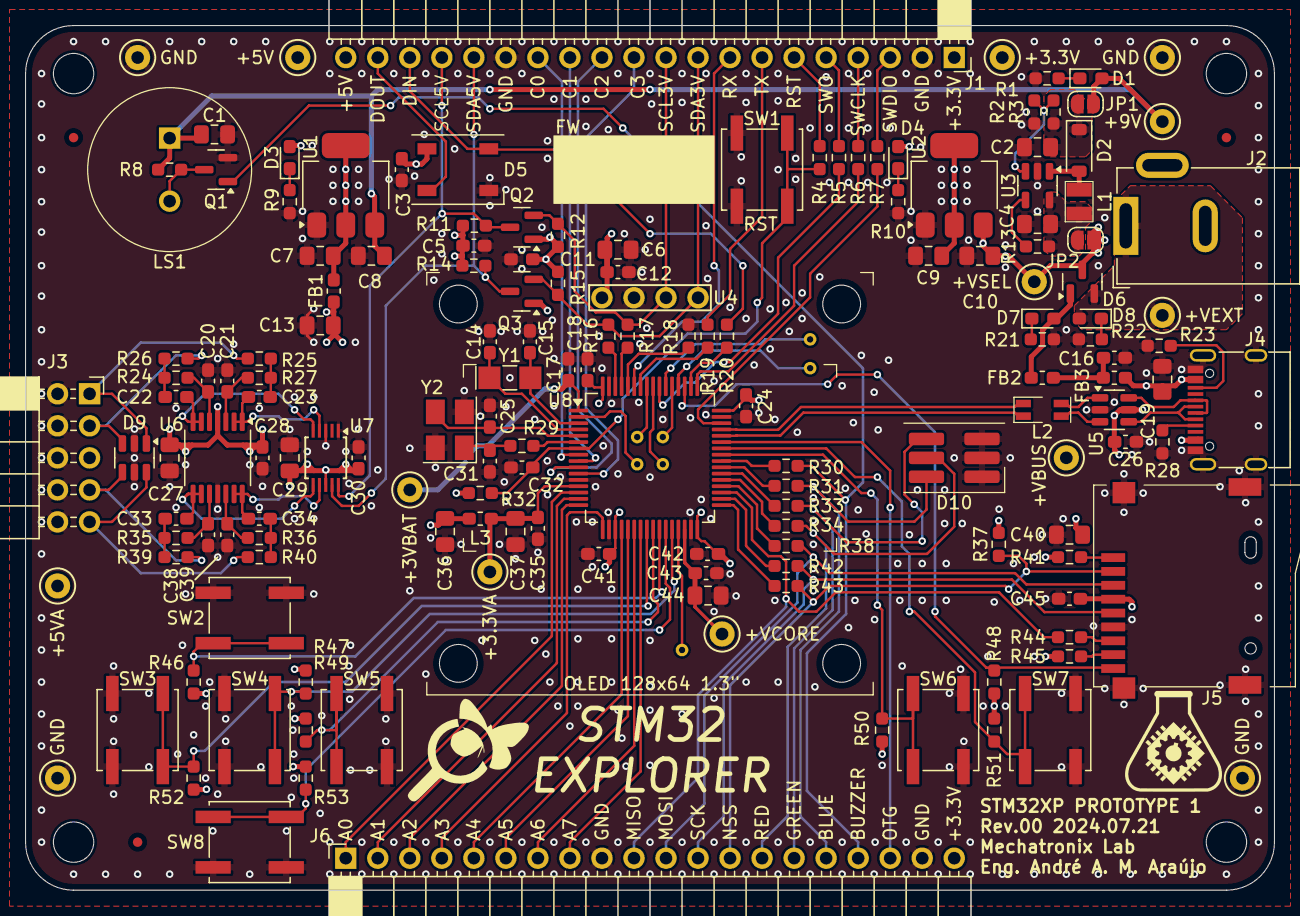
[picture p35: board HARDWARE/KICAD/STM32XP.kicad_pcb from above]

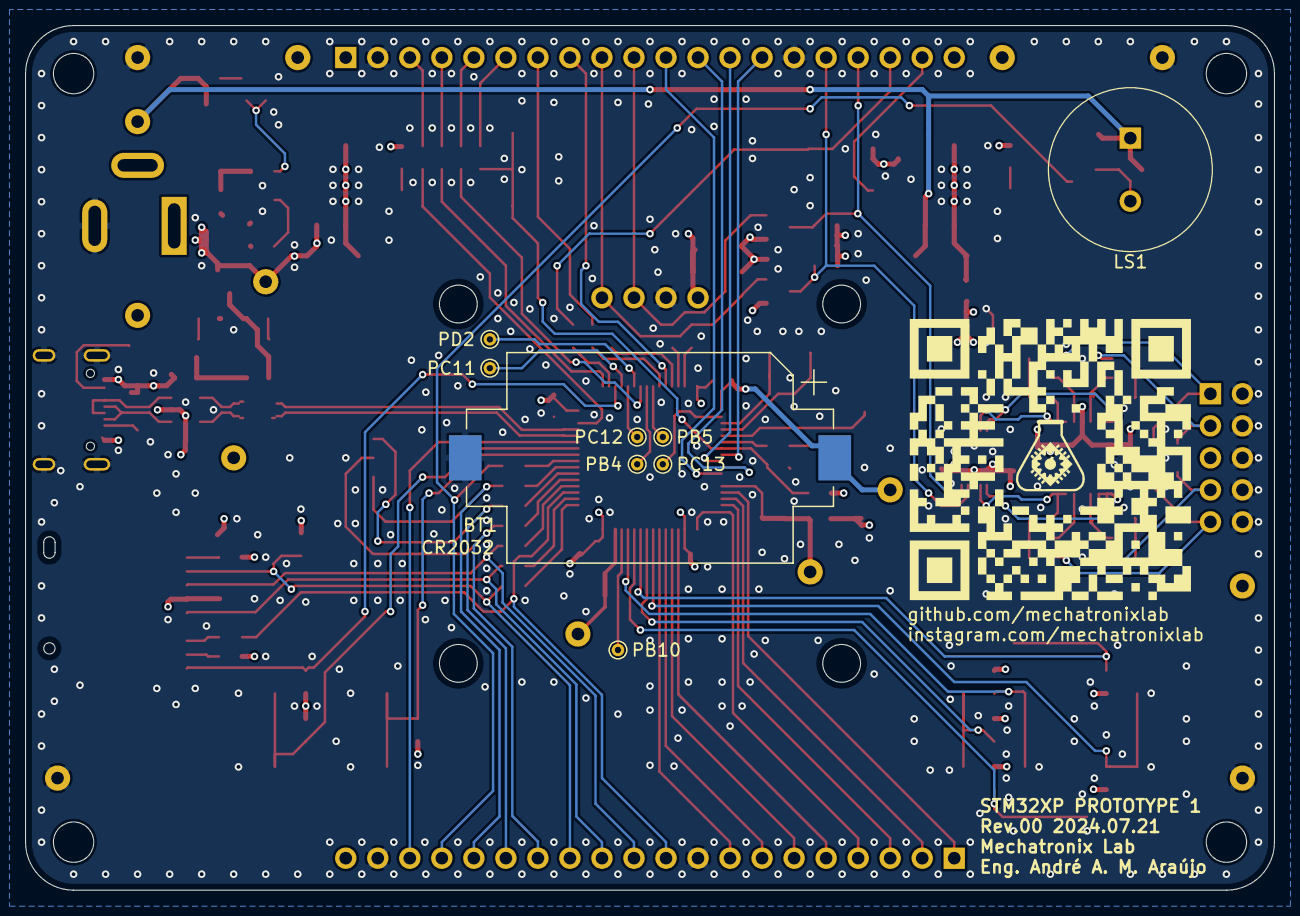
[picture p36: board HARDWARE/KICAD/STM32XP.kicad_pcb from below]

Board: 4 copper layers, 99.1 x 68.6 mm, 173 parts (9 on the bottom side), 120 nets.

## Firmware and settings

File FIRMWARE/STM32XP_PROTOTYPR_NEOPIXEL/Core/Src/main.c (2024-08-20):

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
/* Includes ------------------------------------------------------------------*/
#include "main.h"
#include "dma.h"
#include "tim.h"
#include "gpio.h"

/* USER CODE BEGIN Includes */

#include "isr.h"
#include "led_matrix.h"
#include "rgb.h"
#include "ws2812.h"

/* USER CODE END Includes */


void SystemClock_Config(void);
/**
  * @brief  The application entry point.
  * @retval int
  */
int main(void)
{
  /* MCU Configuration--------------------------------------------------------*/

  /* Reset of all peripherals, Initializes the Flash interface and the Systick. */
  HAL_Init();

  /* Configure the system clock */
  SystemClock_Config();

  /* Initialize all configured peripherals */
  MX_GPIO_Init();
  MX_DMA_Init();
  MX_TIM2_Init();
  /* USER CODE BEGIN 2 */

	LED_init();

	LED_write_matrix();

	RGB_R = 0x10;
	RGB_G = 0;
	RGB_B = 0x10;

	RGB_state = red;

  /* USER CODE END 2 */

  /* Infinite loop */
  /* USER CODE BEGIN WHILE */
  while (1)
  {

	  // shift LED Matrix
	  for (LED_id = 1; LED_id < LED_MATRIX_NUM_LEDS; LED_id++)
	  {
		  LED_matrix_data[LED_MATRIX_NUM_LEDS - LED_id][0] = LED_matrix_data[LED_MATRIX_NUM_LEDS - LED_id - 1][0];
		  LED_matrix_data[LED_MATRIX_NUM_LEDS - LED_id][1] = LED_matrix_data[LED_MATRIX_NUM_LEDS - LED_id - 1][1];
		  LED_matrix_data[LED_MATRIX_NUM_LEDS - LED_id][2] = LED_matrix_data[LED_MATRIX_NUM_LEDS - LED_id - 1][2];
	  }
	  // new color (sweep)
	  RGB_sweep();

	  // Add new color to 1st LED
	  LED_set_color(0, RGB_R, RGB_G, RGB_B);

	  LED_write_matrix();

	  // Delay
	  HAL_Delay(50);

	  HAL_GPIO_TogglePin(LED_RED_GPIO_Port, LED_RED_Pin);

	  // Repeat

    /* USER CODE END WHILE */

    /* USER CODE BEGIN 3 */
  }
  /* USER CODE END 3 */
}

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


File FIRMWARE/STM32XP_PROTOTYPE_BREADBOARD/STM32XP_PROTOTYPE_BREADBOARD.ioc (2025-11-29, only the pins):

Mcu.UserName=STM32F411RETx
PA0-WKUP.Signal=ADCx_IN0
PA1.Signal=ADCx_IN1
PA10.GPIO_Label=ST7789_CS
PA10.Signal=GPIO_Output
PA11.Signal=USB_OTG_FS_DM
PA12.Signal=USB_OTG_FS_DP
PA13.Signal=SYS_JTMS-SWDIO
PA14.Signal=SYS_JTCK-SWCLK
PA15.Signal=S_TIM2_CH1_ETR
PA2.Signal=ADCx_IN2
PA3.Signal=ADCx_IN3
PA5.GPIO_Label=LED_USER
PA5.Signal=GPIO_Output
PA6.GPIO_Label=ST7789_DC
PA6.Signal=GPIO_Output
PA7.GPIO_Label=ST7789_RST
PA7.Signal=GPIO_Output
PA8.GPIO_Label=BUTTON_2
PA8.Signal=GPXTI8
PA9.GPIO_Label=BUTTON_1
PA9.Signal=GPXTI9
PB0.GPIO_Label=BUTTON_UP
PB0.Signal=GPXTI0
PB1.GPIO_Label=BUTTON_DOWN
PB1.Signal=GPXTI1
PB10.Signal=S_TIM2_CH3
PB12.GPIO_Label=SD_CS
PB12.Signal=GPIO_Output
PB13.Signal=SPI2_SCK
PB14.Signal=SPI2_MISO
PB15.Signal=SPI2_MOSI
PB2.GPIO_Label=BUTTON_CENTER
PB2.Signal=GPXTI2
PB3.Signal=SYS_JTDO-SWO
PB5.GPIO_Label=OLED_RST
PB5.Signal=GPIO_Output
PB6.Signal=USART1_TX
PB7.Signal=USART1_RX
PB8.Signal=I2C1_SCL
PB9.Signal=I2C1_SDA
PC10.GPIO_Label=SD_NIN
PC10.Signal=GPIO_Input
PC13-ANTI_TAMP.GPIO_Label=BUTTON_USER
PC13-ANTI_TAMP.Signal=GPXTI13
PC14-OSC32_IN.Signal=RCC_OSC32_IN
PC15-OSC32_OUT.Signal=RCC_OSC32_OUT
PC4.GPIO_Label=BUTTON_LEFT
PC4.Signal=GPXTI4
PC5.GPIO_Label=BUTTON_RIGHT
PC5.Signal=GPXTI5
PC6.Signal=S_TIM3_CH1
PC7.Signal=S_TIM3_CH2
PC8.Signal=S_TIM3_CH3
PC9.Signal=S_TIM3_CH4

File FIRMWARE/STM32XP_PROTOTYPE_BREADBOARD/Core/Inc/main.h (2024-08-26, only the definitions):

#define BUTTON_USER_Pin GPIO_PIN_13
#define BUTTON_USER_GPIO_Port GPIOC
#define BUTTON_USER_EXTI_IRQn EXTI15_10_IRQn
#define LED_USER_Pin GPIO_PIN_5
#define LED_USER_GPIO_Port GPIOA
#define ST7789_DC_Pin GPIO_PIN_6
#define ST7789_DC_GPIO_Port GPIOA
#define ST7789_RST_Pin GPIO_PIN_7
#define ST7789_RST_GPIO_Port GPIOA
#define BUTTON_LEFT_Pin GPIO_PIN_4
#define BUTTON_LEFT_GPIO_Port GPIOC
#define BUTTON_LEFT_EXTI_IRQn EXTI4_IRQn
#define BUTTON_RIGHT_Pin GPIO_PIN_5
#define BUTTON_RIGHT_GPIO_Port GPIOC
#define BUTTON_RIGHT_EXTI_IRQn EXTI9_5_IRQn
#define BUTTON_UP_Pin GPIO_PIN_0
#define BUTTON_UP_GPIO_Port GPIOB
#define BUTTON_UP_EXTI_IRQn EXTI0_IRQn
#define BUTTON_DOWN_Pin GPIO_PIN_1
#define BUTTON_DOWN_GPIO_Port GPIOB
#define BUTTON_DOWN_EXTI_IRQn EXTI1_IRQn
#define BUTTON_CENTER_Pin GPIO_PIN_2
#define BUTTON_CENTER_GPIO_Port GPIOB
#define BUTTON_CENTER_EXTI_IRQn EXTI2_IRQn
#define SD_CS_Pin GPIO_PIN_12
#define SD_CS_GPIO_Port GPIOB
#define BUTTON_2_Pin GPIO_PIN_8
#define BUTTON_2_GPIO_Port GPIOA
#define BUTTON_2_EXTI_IRQn EXTI9_5_IRQn
#define BUTTON_1_Pin GPIO_PIN_9
#define BUTTON_1_GPIO_Port GPIOA
#define BUTTON_1_EXTI_IRQn EXTI9_5_IRQn
#define ST7789_CS_Pin GPIO_PIN_10
#define ST7789_CS_GPIO_Port GPIOA
#define SD_NIN_Pin GPIO_PIN_10
#define SD_NIN_GPIO_Port GPIOC
#define OLED_RST_Pin GPIO_PIN_5
#define OLED_RST_GPIO_Port GPIOB

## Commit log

2024-04-27 Started hardware design. Created IOC file on CubeMX. Created KiCad project.
    [STM32XP.kicad_pcb, STM32XP.kicad_sch]
2024-04-28 Continuing schematic design and preliminary placement of components.
    [STM32XP.kicad_pcb, STM32XP.kicad_sch]
2024-05-07 Added libraries for custom components. Added OLED display. Started draft of routing.
    [STM32XP.kicad_pcb, STM32XP.kicad_sch]
2024-05-11 Folders reorganization.
    [STM32XP.kicad_pcb, STM32XP.kicad_sch]
2024-05-11 Preparation to start CubeIDE Project and prototype testing.
    [STM32XP.kicad_pcb]
2024-05-11 Firmware project creation for breadboard prototype.
2024-05-11 Added logo and legend to board. Added OLED display libs to firmware.
    [STM32XP.kicad_pcb]
2024-05-12 Added PWM functionality and tested using buzzer and RGB LED.
    [STM32XP_PROTOTYPE_BREADBOARD.ioc]
2024-05-12 Added timed interrupt.
2024-05-12 Added external interrupt to ISR; still needs debouncing.
2024-05-13 Added RGBfunctionality. Corrected SPI connections on schematic and layout.
    [STM32XP.kicad_pcb, STM32XP.kicad_sch]
2024-05-18 Added buttons debouncing.
2024-05-19 Added AFE circuit.
    [STM32XP.kicad_pcb, STM32XP.kicad_sch]
2024-05-19 Added PWM outputs from MCU; added directional buttons; added part of buzzer circuit.
    [STM32XP.kicad_pcb, STM32XP.kicad_sch]
2024-07-08 Added sheets and organized schematic; added DC-DC Boost Converter; added connections to headers; general improvements on schematic and layout.
    [ANALOG.kicad_sch, INTERFACE.kicad_sch, IO.kicad_sch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]
2024-07-10 Continuing layout and routing.
    [ANALOG.kicad_sch, INTERFACE.kicad_sch, IO.kicad_sch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]
2024-07-11 Added new PNs for some components. Overall improvements in schematic and layout.
    [POWER.kicad_sch, STM32XP.kicad_pcb, WE-LQS_252012 (rev1).igs]
2024-07-13 Continuing PCB layout and routing.
    [STM32XP.kicad_pcb]
2024-07-14 Trying to solve all errors on DRC, but some depend on finishing other tasks.
    [ANALOG.kicad_sch, INTERFACE.kicad_sch, IO.kicad_sch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]
2024-07-15 Changed tactile switch model; had to enlarge board and adjust positioning of components; added some 3D models and comments with PNs for further reference; general layout and routing improvements.
    [ANALOG.kicad_sch, INTERFACE.kicad_sch, IO.kicad_sch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]
2024-07-15 More improvements. Added 3D models. Added legends.
    [IO.kicad_sch, POWER.kicad_sch, STM32XP.kicad_pcb]
2024-07-16 Added stiching vias.
    [STM32XP.kicad_pcb]
2024-07-17 Added fiducial marks.
    [MECHANICAL.kicad_sch, STM32XP.kicad_pcb]
2024-07-20 Improvements to layout. Fixed most of errors and warnings. Added correct footprint for Micro SD socket. Added markings and symbols to legend.
    [IO.kicad_sch, STM32XP.kicad_pcb]
2024-07-21 Finished PCB design, but needs to be reviewed. Added all components and PNs that were missing or incorrect. Added draft of STM32 EXPLORER logo.
    [ANALOG.kicad_sch, Display_OLED_SSD1306_1.3inch.STEP, INTERFACE.kicad_sch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]
2024-07-21 Finished Revision 0 design. Used plugin to make manufacturing files. Purchased 5 units in JLCPCB. Let's wait to check the results! :D
    [ANALOG.kicad_sch, INTERFACE.kicad_sch, IO.kicad_sch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]
2024-08-06 Started Prototype 1 board bring-up.
2024-08-07 Added PDF of the schematic. Fixed clock configuration to run the MCU from 12 MHz HSE. Tested UART, RGB, Buttons, SD Card, OLED, Buzzer, external ACD and AA filter... all good (OLED requires minor bug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
    [STM32XP_PROTOTYPE_BREADBOARD.ioc, ads1115.c, main.c]
2024-08-09 Added comments about minor adjustments needed after board assembly.
    [INTERFACE.kicad_sch, POWER.kicad_sch, STM32XP.kicad_pcb]
2024-08-10 Added USB CDC basic driver.
2024-08-20 Added NeoPixel driver.
2024-08-24 Added RTC to OLED display. Fixed frame offset of SH1106 OLED controller. Added internal ADC (needs refactoring).
    [STM32XP_PROTOTYPE_BREADBOARD.ioc, isr.c]
2024-11-03 Added updated PDF with comments after corrections in the prototype.
    [INTERFACE.kicad_sch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]
2024-11-08 Added complete BOM.
    [STM32XP - BOM REV.00.xlsx, STM32XP.kicad_pcb]
2024-12-07 Preparing code for demonstration for PCB Course.
    [STM32XP - BOM REV.00.xlsx]
2024-12-07 Don't now why these files changed.
    [STM32XP.kicad_pcb, STM32XP.kicad_sch]
2024-12-07 Fixed SD Card. It uses LOW polarity, but display uses HIGH.
    [STM32XP_PROTOTYPE_BREADBOARD.ioc, rtcc.c]
2025-01-19 Added new Mechatronix Lab logo; tested firmwre on PCB Course board.
2025-01-19 Added board images.
2025-05-18 Update README.md
    Adding info about the breadbaord prototype
2025-11-29 Fixed undefined input that was messing LEDs associated with buttons (activated internal pullup to BUTTON_USER (PC13).
    [STM32XP_PROTOTYPE_BREADBOARD.ioc]

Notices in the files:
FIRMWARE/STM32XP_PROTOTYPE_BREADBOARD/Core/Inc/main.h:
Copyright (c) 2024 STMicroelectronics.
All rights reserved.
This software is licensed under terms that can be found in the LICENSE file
